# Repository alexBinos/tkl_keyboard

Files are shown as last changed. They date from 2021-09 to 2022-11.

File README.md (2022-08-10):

# tkl_keyboard

A custom tenkeyless keyboard with extra hardware features including;

- ATMEGA32U4 microcontroller compatible with QMK firmware
- 2x optional rotary encoders
- I2C breakout to support an OLED display
- Per-key RGB LED lighting and underglow lighting
- Hot-swap key switch sockets
- 4 port USB 2.0 HUB with 3 spare downstream ports
- Optional external power circuit supplying up to 2A for USB downstream and onboard power requirements

<br>

See `Firmware/` for example QMK projects. Note that some pin assignments changed between v0 and v1, see `Documents/tkl_keyboard v1 changes.md`. Pre-built binaries for the default configurations are also provided in `Firmware/bin`.

<br>

There are two versions of the case, both are compatible with hardware v0 and v1. The v1 case is a more integrated design, easier to assemble and can be positioned at a number of different angles.

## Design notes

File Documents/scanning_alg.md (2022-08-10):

# Matrix scanning algorithm

The matrix scanning algorithm uses negative logic to detect key presses, ie. reading a 0 indicates that a switch has been pressed and driving an output to 0 is to drive it to the 'active' state.
The switch matrix diodes are placed facing from row to column so current can flow in this direction only. The columns are driven as outputs and the rows are read as inputs, the default state is no columns driven, ie. all column outputs are driven to the 1 'inactive' state and the row inputs are allowed to float high by their internal pull-up resistor.
The matrix is scanned with the following method;

1. Drive the first column output low while leaving all other column outputs high
2. Read back all row values simultaneously
3. Drive the current column high
4. Drive the next column low while leaving all other column outputs high
5. Repeat from step 2

When a switch is pressed, the path between the microcontrollers internal pull-up resistor and the diode is closed. When the corresponding column drives low the diode is allowed to conduct and a low is seen at the microcontroller row input pin. The columns are scanned much faster than a switch press event to guarantee that every switch press is captured.

A switch press event is processed when the rows are read back; if one or more of the row values are low then the switch(s) located at position (row, col) is being pressed. Note that the diodes allow any keyswitch combination to be decoded uniquely. Since the switch press is recorded in negative logic, the final result is inverted in the firmware before handing over to the switch decoding logic where the matrix position is mapped to a key switch value.

<p align="center" width="100%">
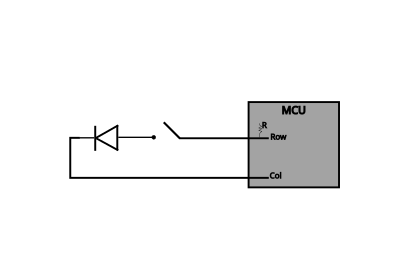
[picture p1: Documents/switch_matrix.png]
     
</p>

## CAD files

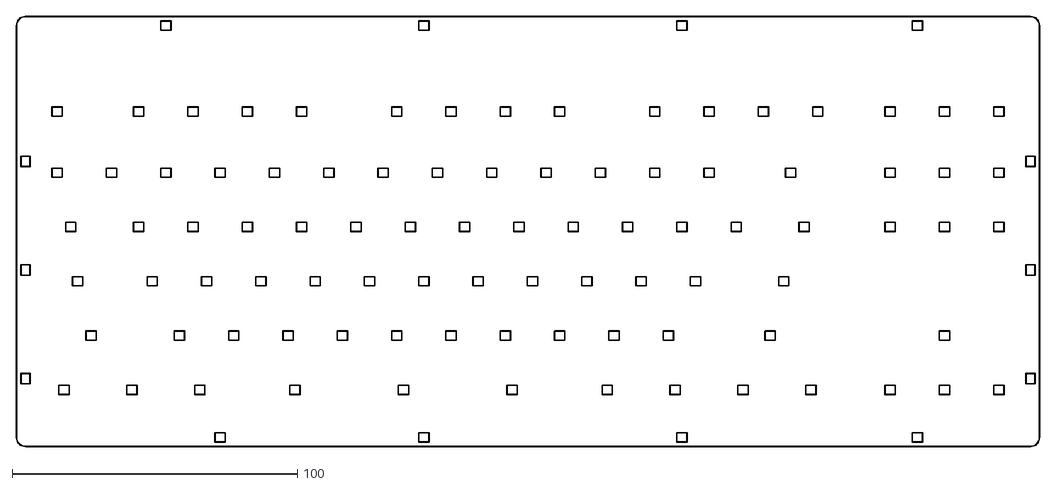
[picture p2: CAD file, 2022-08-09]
Mechanical/dxf/tkl_keyboard-Edge_Cuts.dxf
358.8 x 150.9

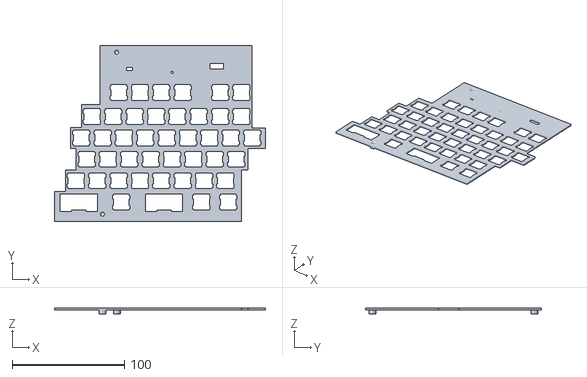
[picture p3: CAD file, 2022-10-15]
Mechanical/v1/tkl_keyframe_middle.STL
188.2 x 156.9 x 5.40

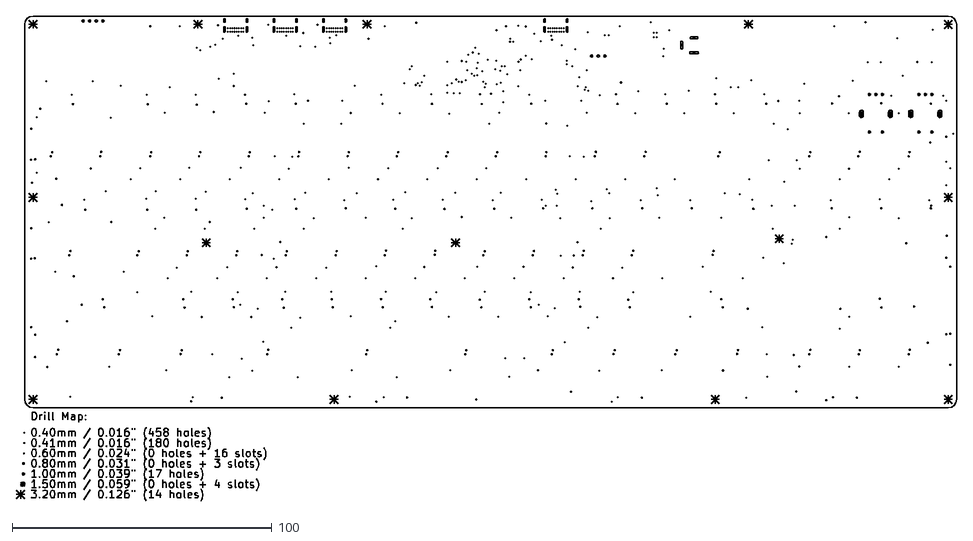
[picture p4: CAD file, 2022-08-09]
Mechanical/dxf/tkl_keyboard-PTH-drl_map.dxf
362.0 x 186.7

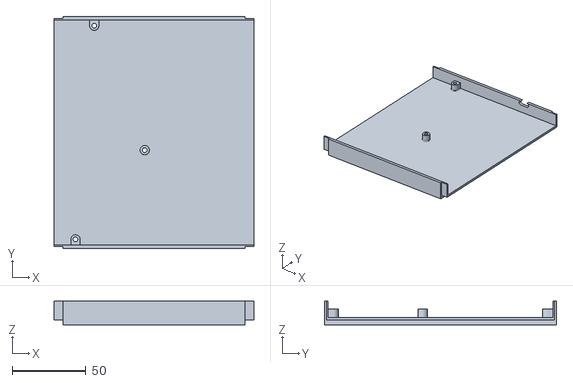
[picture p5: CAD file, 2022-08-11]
Mechanical/v1/tkl_case_middle.STL
135.2 x 156.9 x 16.0

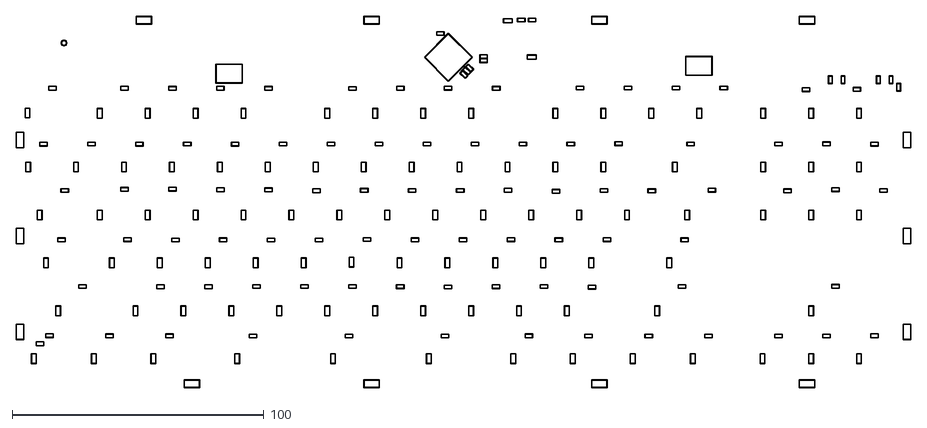
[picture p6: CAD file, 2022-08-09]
Mechanical/dxf/tkl_keyboard-B_CrtYd.dxf
355.5 x 147.5

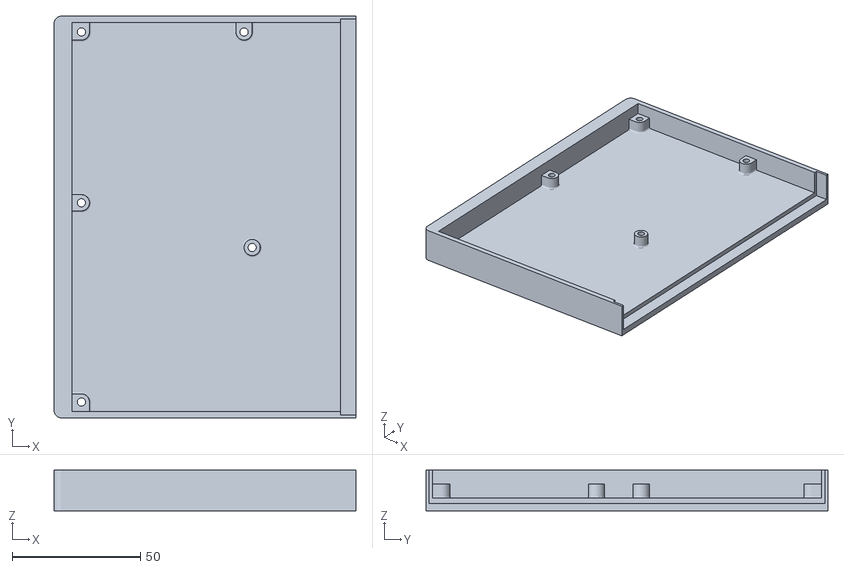
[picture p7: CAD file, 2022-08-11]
Mechanical/v1/tkl_case_left.STL
117.9 x 156.9 x 16.0

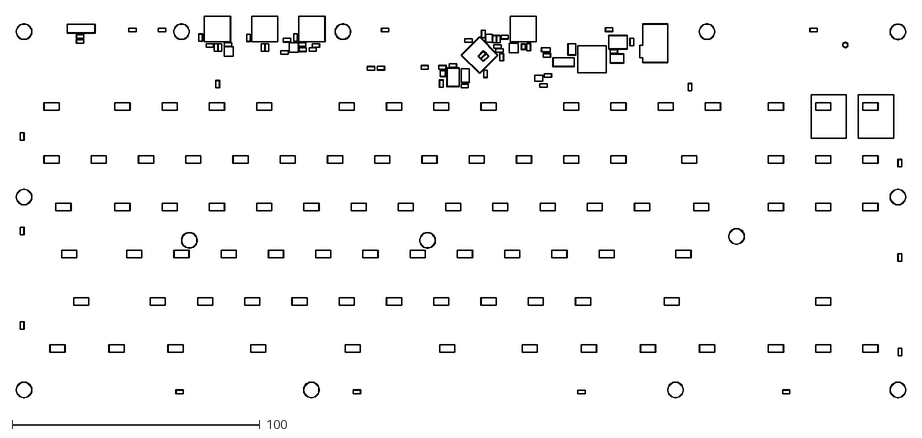
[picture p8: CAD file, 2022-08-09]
Mechanical/dxf/tkl_keyboard-F_CrtYd.dxf
358.7 x 153.8

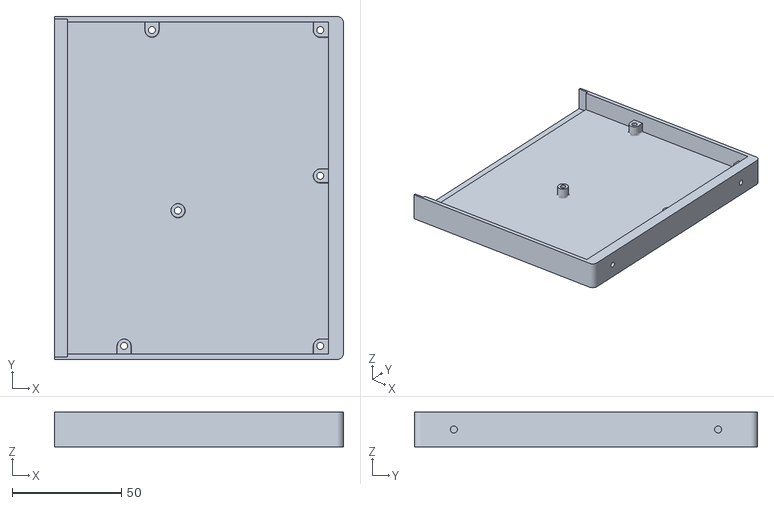
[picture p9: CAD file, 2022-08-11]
Mechanical/v1/tkl_case_right.STL
132.3 x 156.9 x 16.0

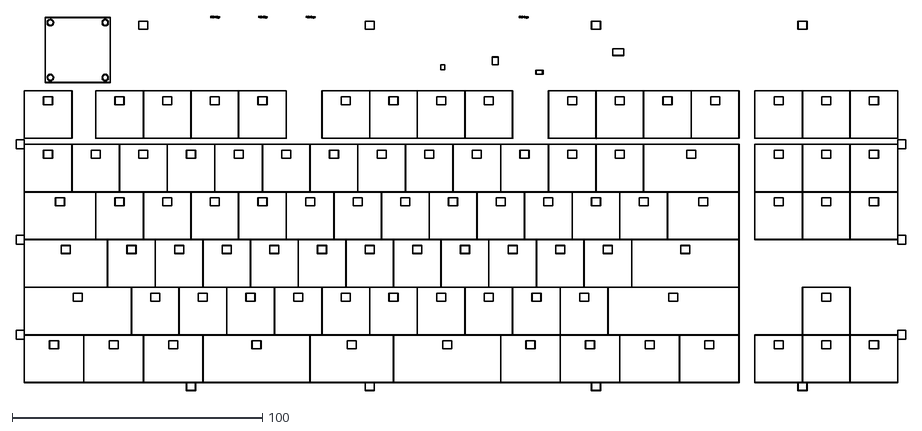
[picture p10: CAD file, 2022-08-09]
Mechanical/dxf/tkl_keyboard-Dwgs_User.dxf
355.7 x 149.6

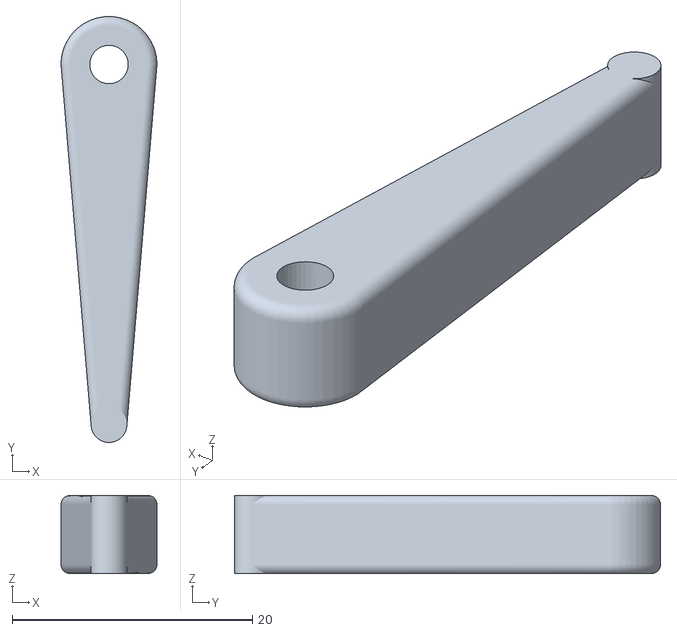
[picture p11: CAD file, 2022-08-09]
Mechanical/v1/tkl_stand.STL
8.00 x 35.5 x 6.50

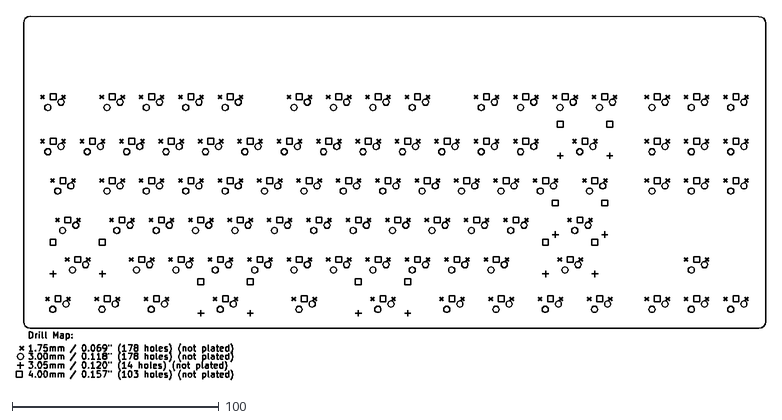
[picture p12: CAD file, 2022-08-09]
Mechanical/dxf/tkl_keyboard-NPTH-drl_map.dxf
362.2 x 175.5

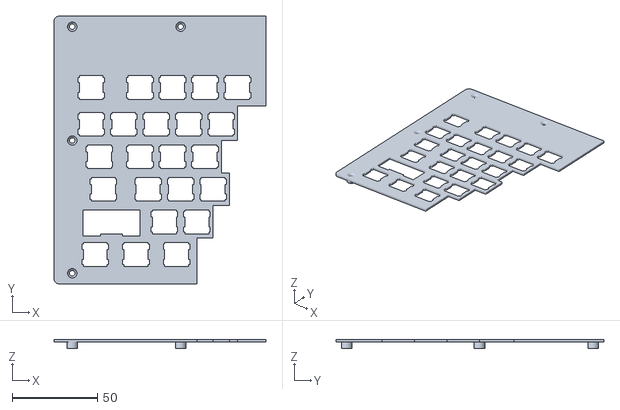
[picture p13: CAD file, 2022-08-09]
Mechanical/v1/tkl_keyframe_left.STL
124.2 x 156.9 x 5.40

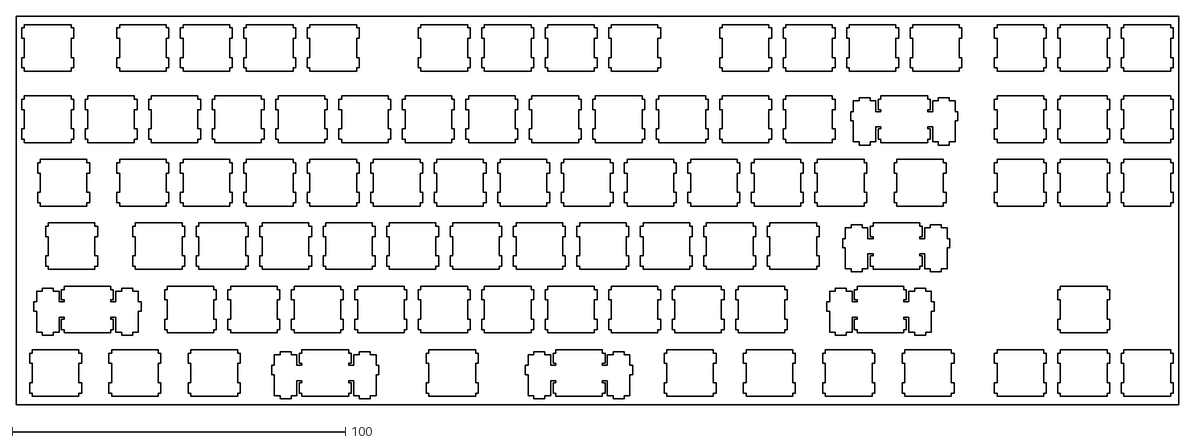
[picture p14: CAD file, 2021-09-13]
Mechanical/dxf/mx_key_frame_swillkb.dxf
349.2 x 116.7

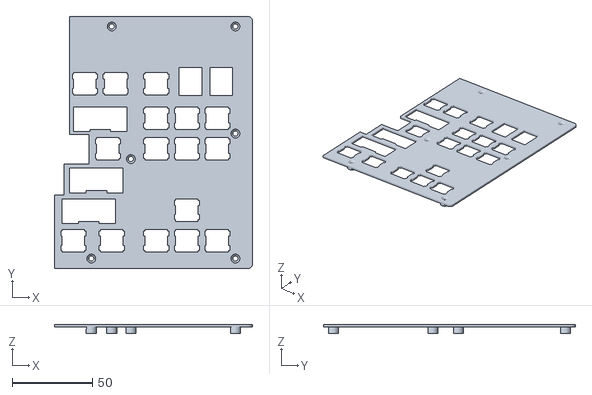
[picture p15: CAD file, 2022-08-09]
Mechanical/v1/tkl_keyframe_right.STL
123.4 x 156.9 x 5.40

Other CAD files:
Mechanical/v0/tkl_bottom_middle.STL
Mechanical/v0/tkl_bottom_right.STL
Mechanical/v0/tkl_key_frame_middle.STL
Mechanical/v0/tkl_bottom_left.STL
Mechanical/v0/tkl_key_frame_left.STL
Mechanical/v0/tkl_key_frame_right.STL
Mechanical/v0/tkl_spacer.STL

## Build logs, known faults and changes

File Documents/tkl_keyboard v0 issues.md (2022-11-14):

## TKL Keyboard v0 issues

<br>

1. I2C lines connected incorrectly to ATMEGA32U4

The I2C lines are not connected to the dedicated I2C hardware pins PD1 and PD0 on the ATMEGA32U4. The OLED display cannot be driven on the v0 board.

*Fixes:* Cannot be fixed in hardware as the dedicated I2C pins are used to drive the switch matrix.

2. Line decoders are never disabled

In order for the matrix scanning algorithm to work correctly, each line decoder output needs to be disabled (set to 0xFF) while the other side of the matrix is being scanned.

*Fixes:* This can be achieved by driving pin 6, E3 low. Pins from rotary encoder 2 were repurposed to make this connection on the v0 board. The V1 board features just 2 rotary encoders as a result.

<p align="center" width="100%">
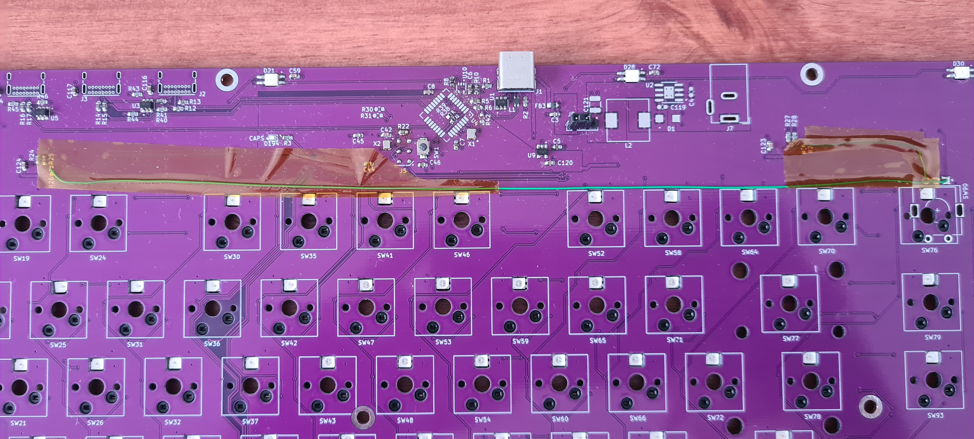
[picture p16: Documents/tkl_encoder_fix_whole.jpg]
    
</p>

<p align="center" width="100%">
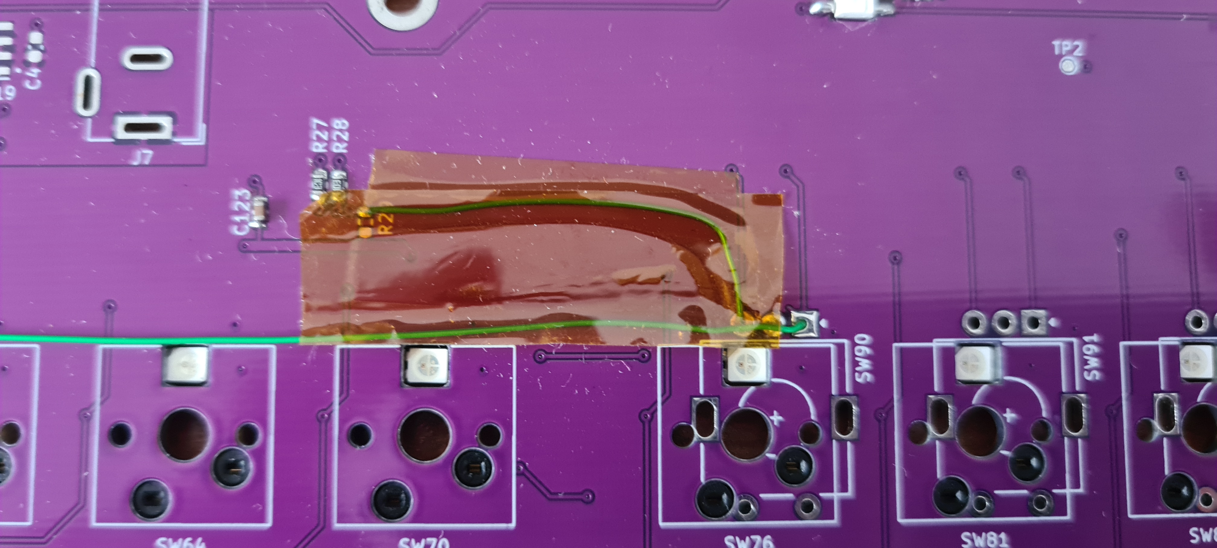
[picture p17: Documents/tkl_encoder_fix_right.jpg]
    
</p>

<p align="center" width="100%">
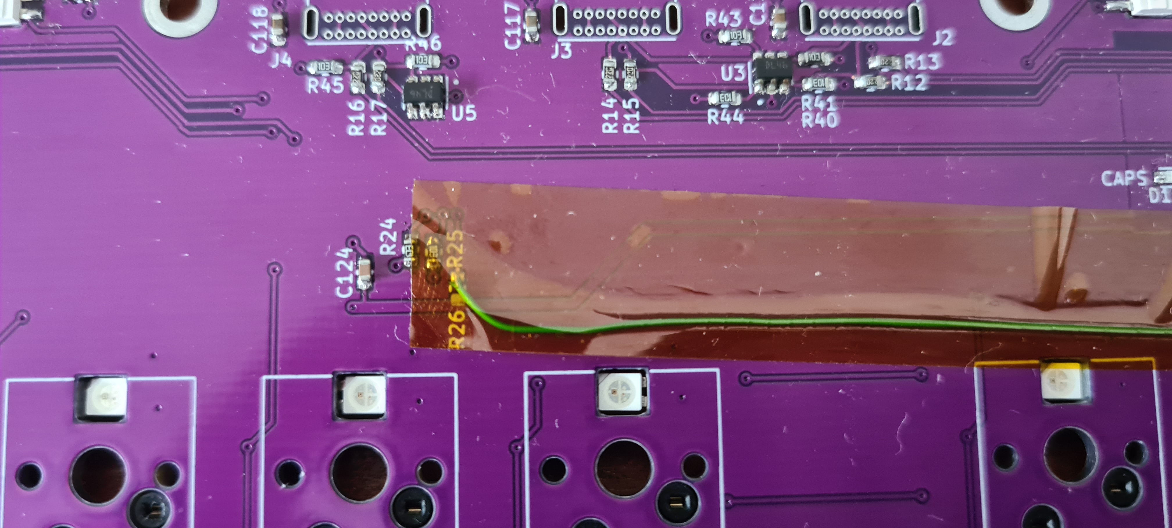
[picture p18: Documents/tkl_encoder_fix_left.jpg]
    
</p>

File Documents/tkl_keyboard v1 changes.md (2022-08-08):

## TKL Keyboard v1 changes

<br>

   1. Moved I2C lines to PD1/SDA and PD0/SCL
   2. Removed line decoder strap resistors
   3. Disconnected mouting holes from ground
   4. Rounded corners on +3V3 plane

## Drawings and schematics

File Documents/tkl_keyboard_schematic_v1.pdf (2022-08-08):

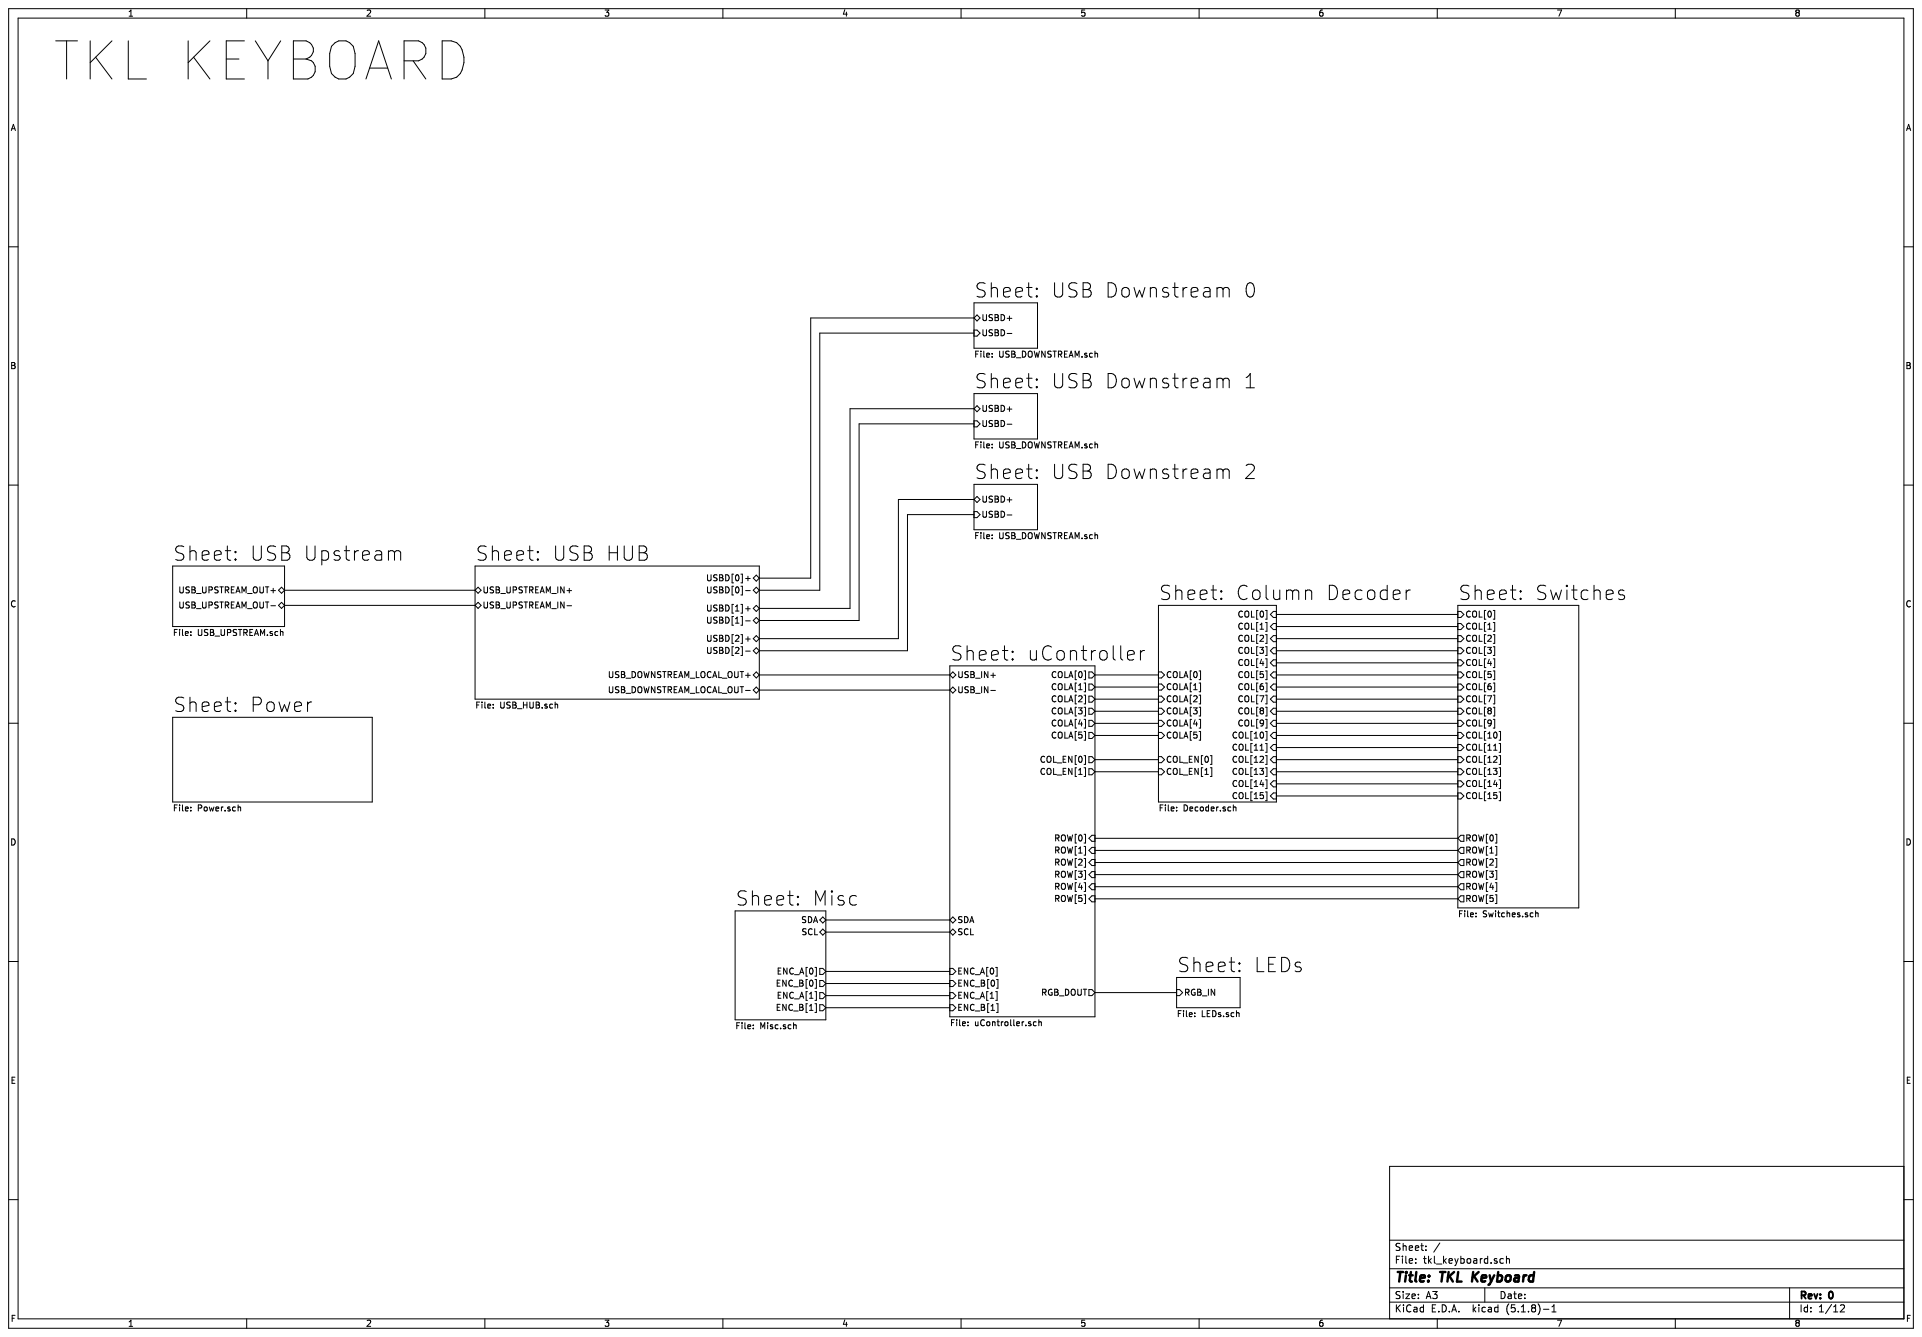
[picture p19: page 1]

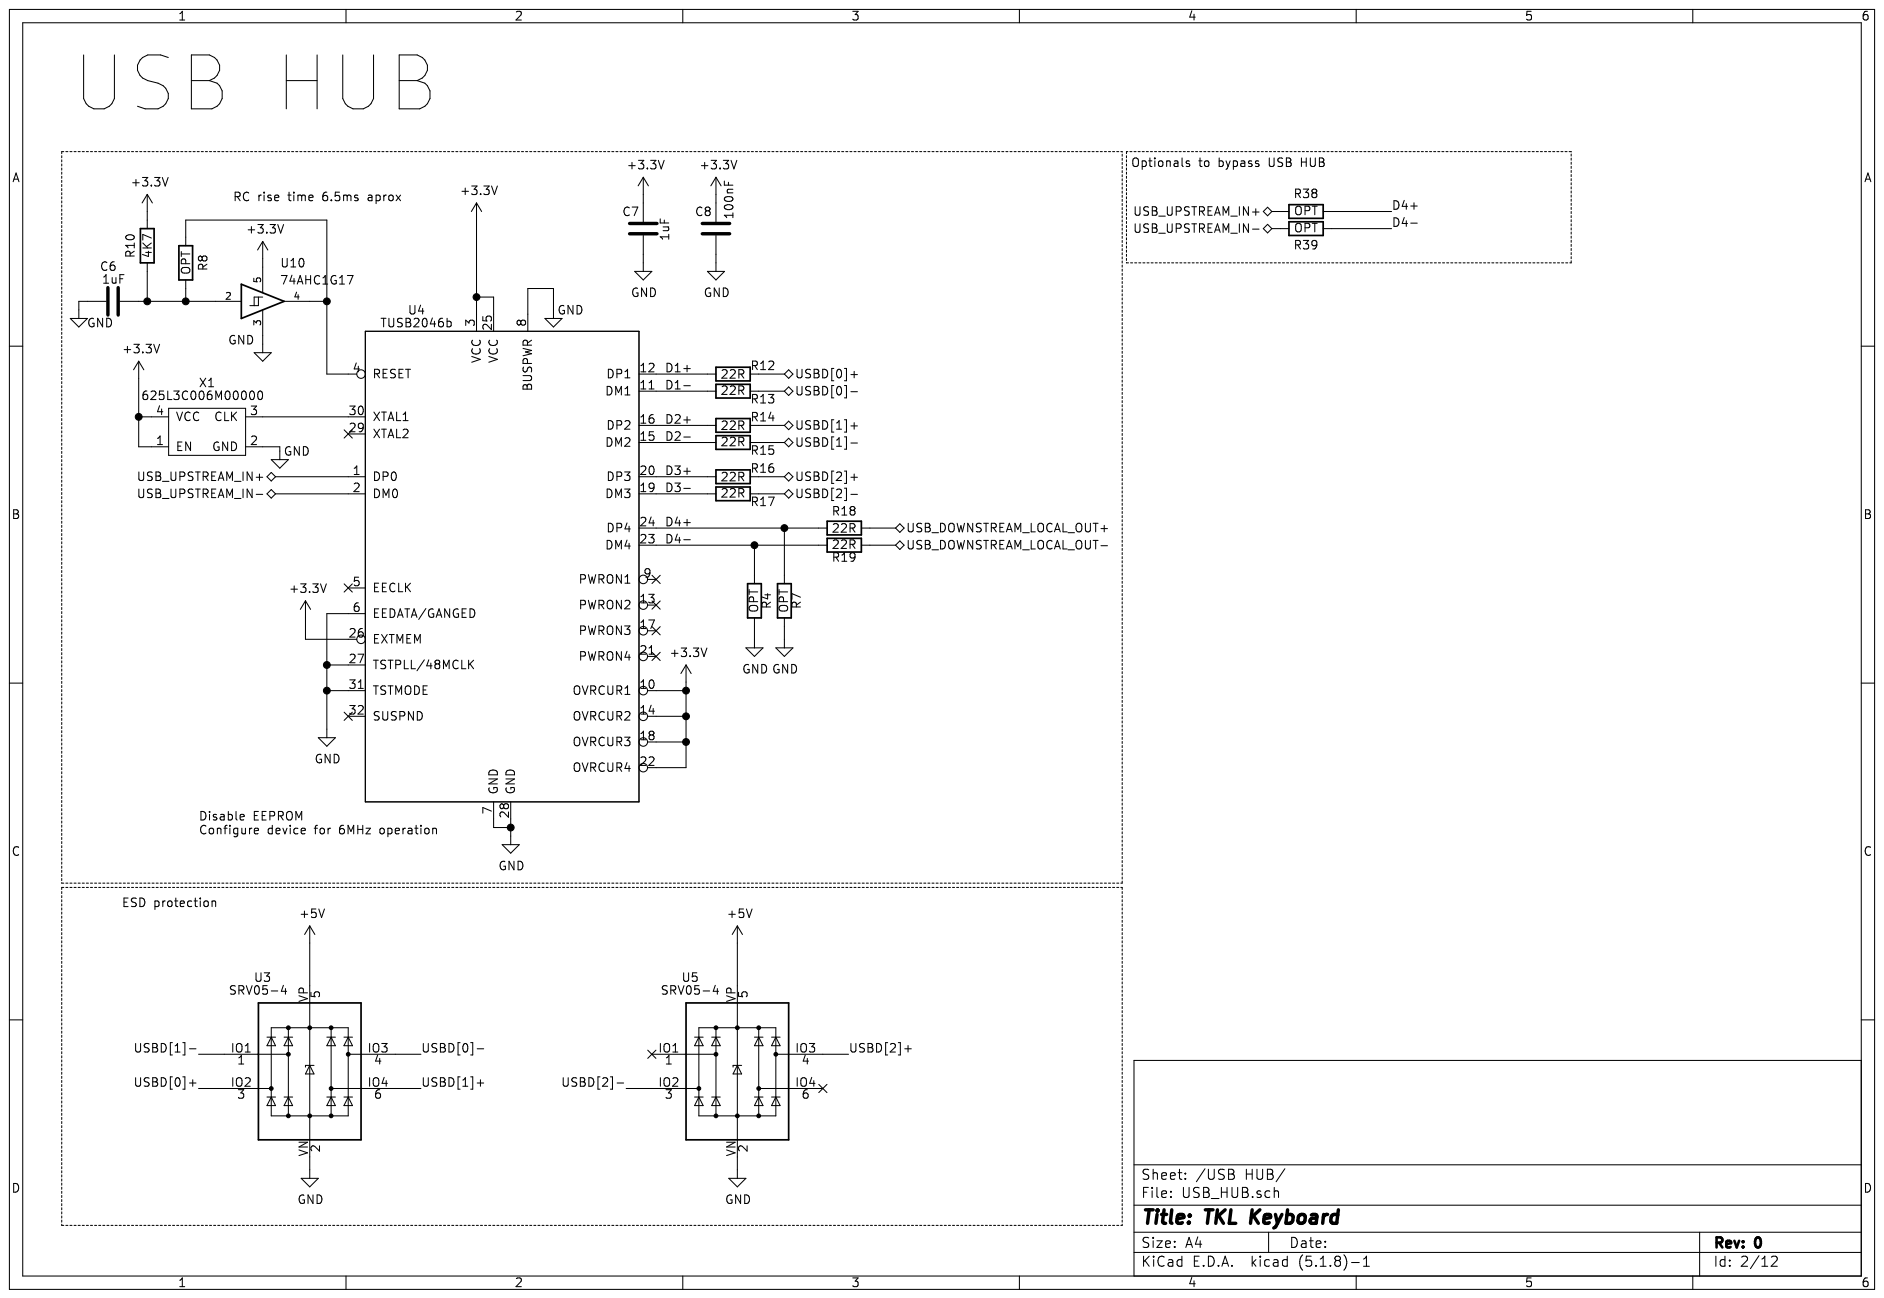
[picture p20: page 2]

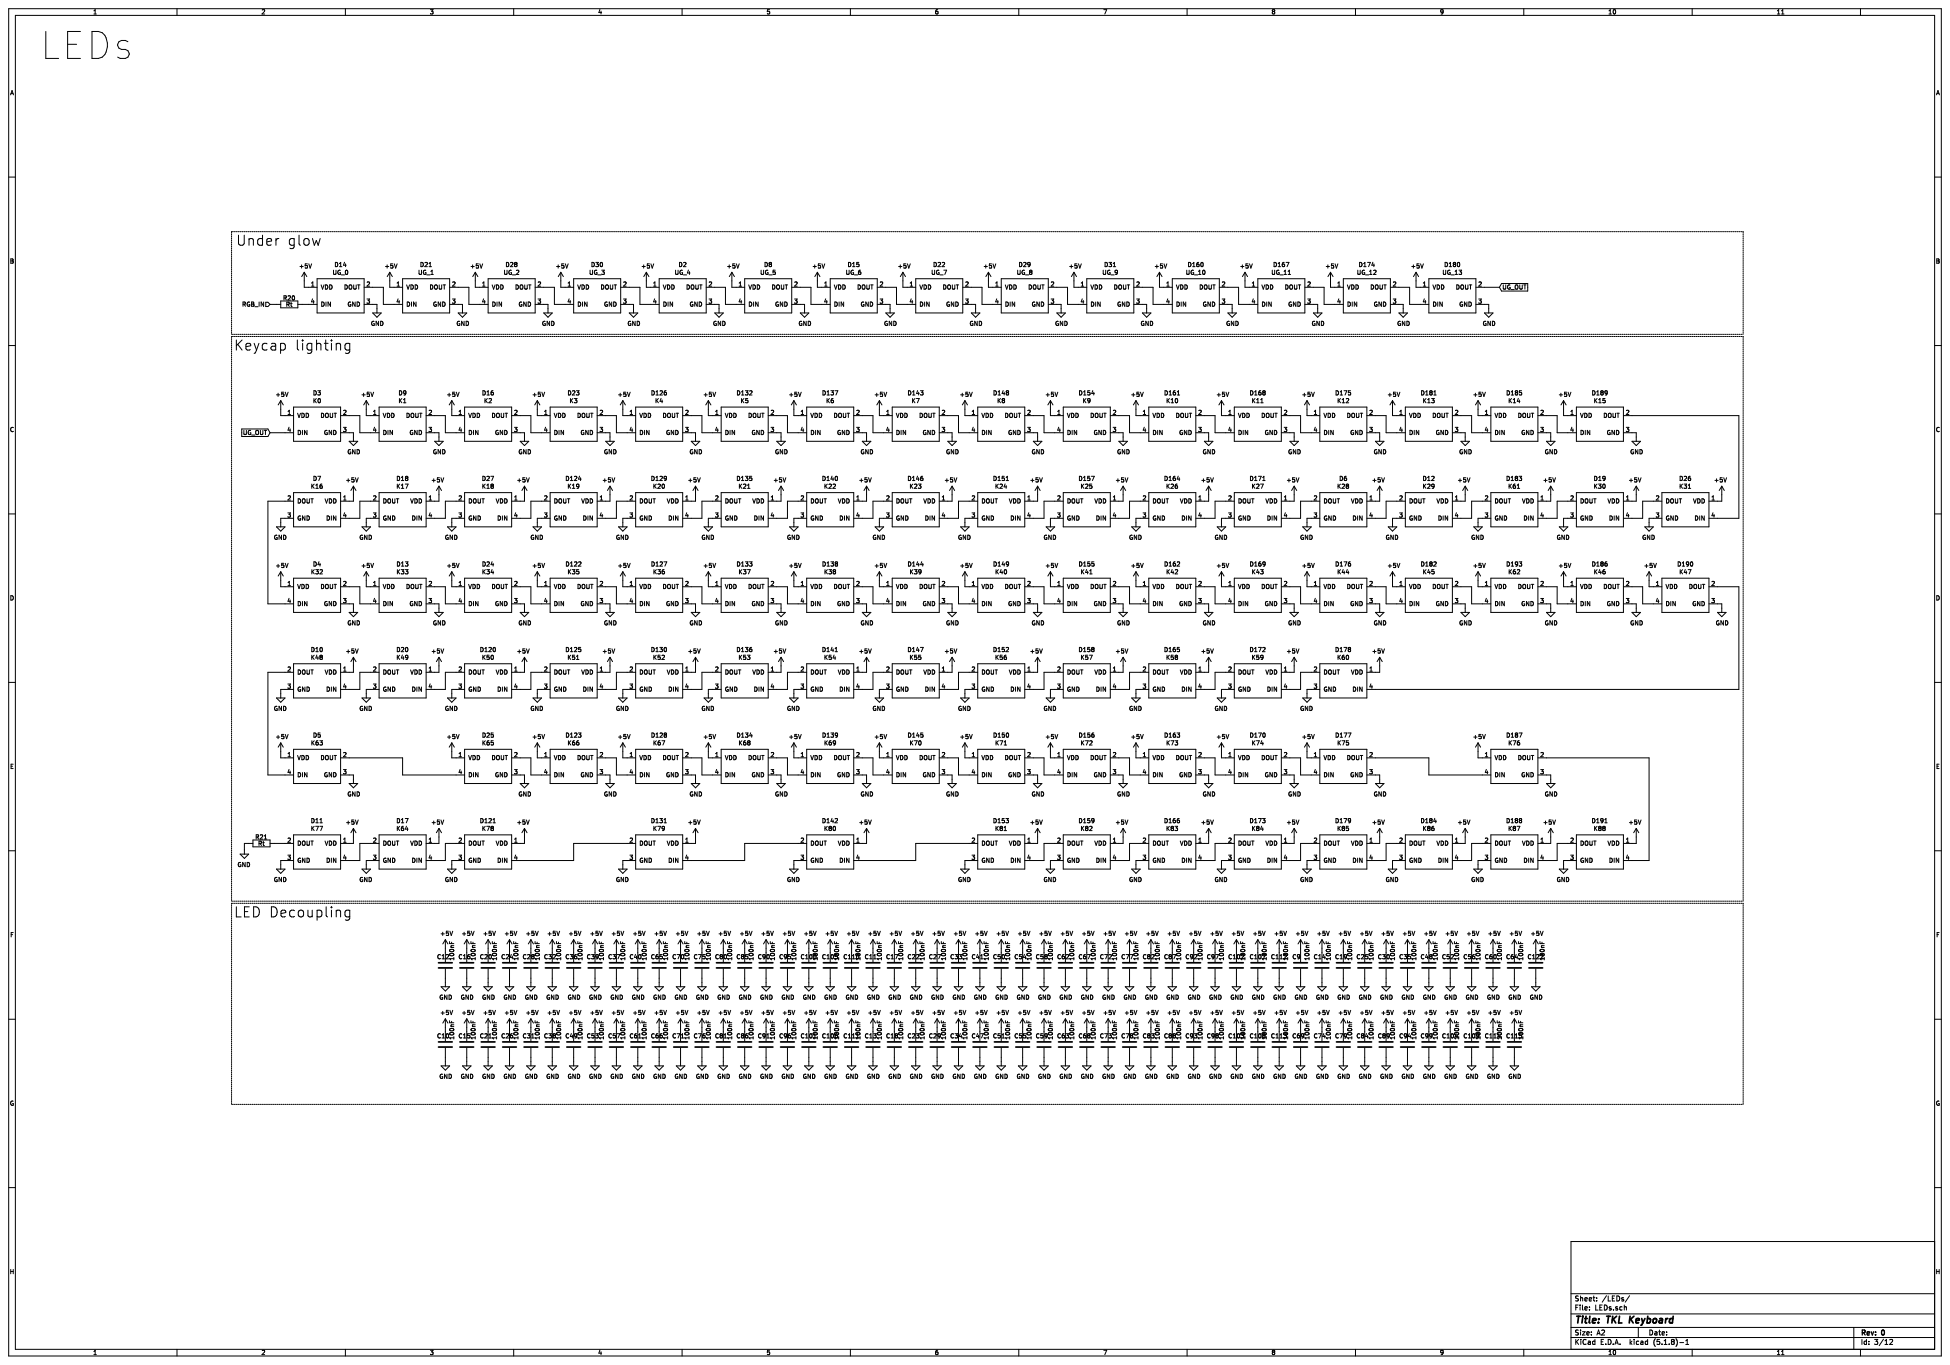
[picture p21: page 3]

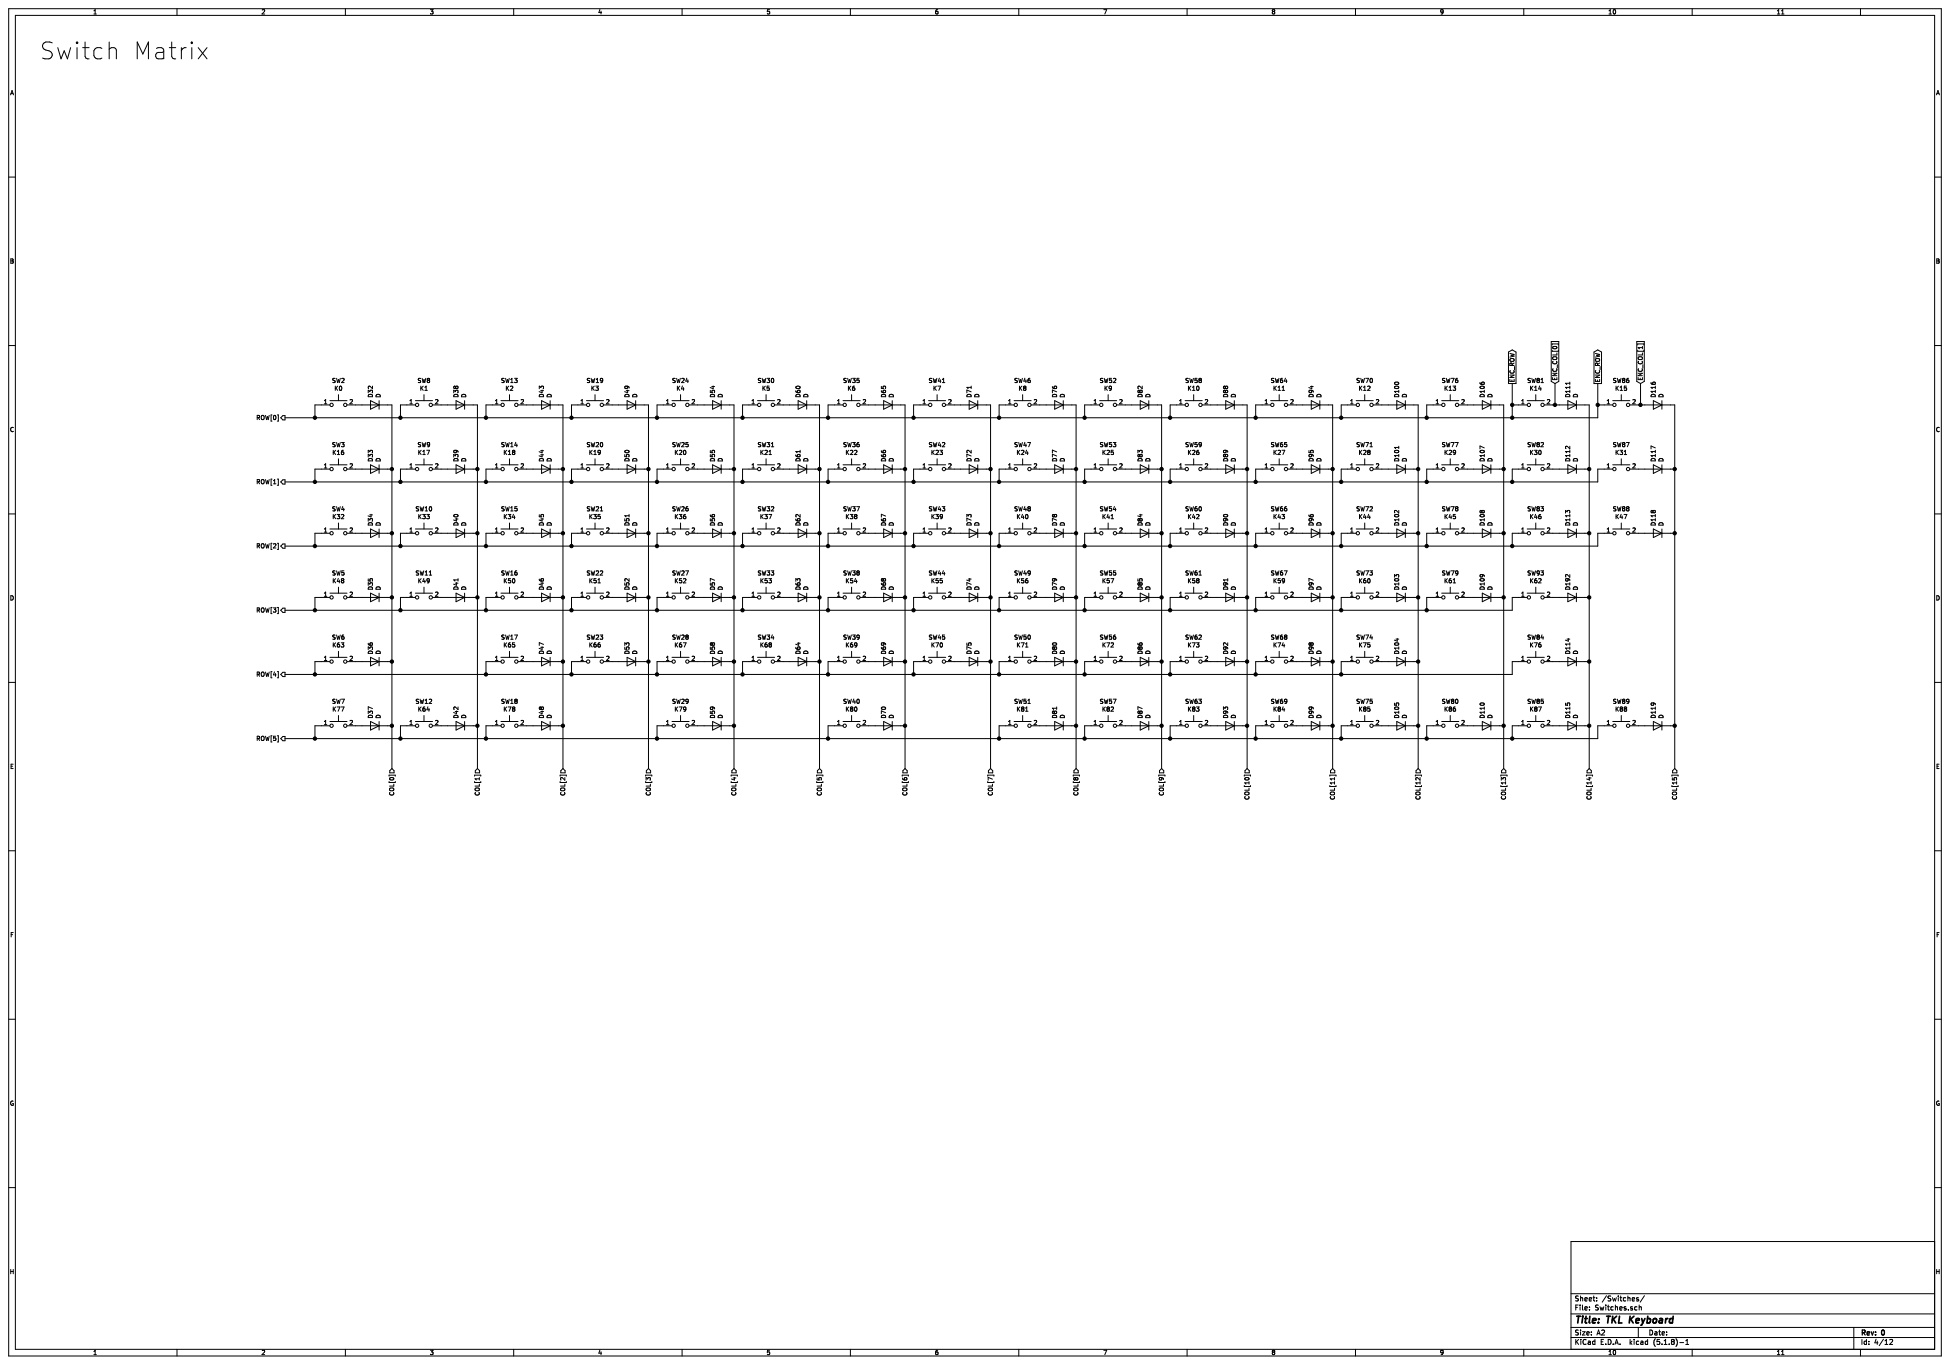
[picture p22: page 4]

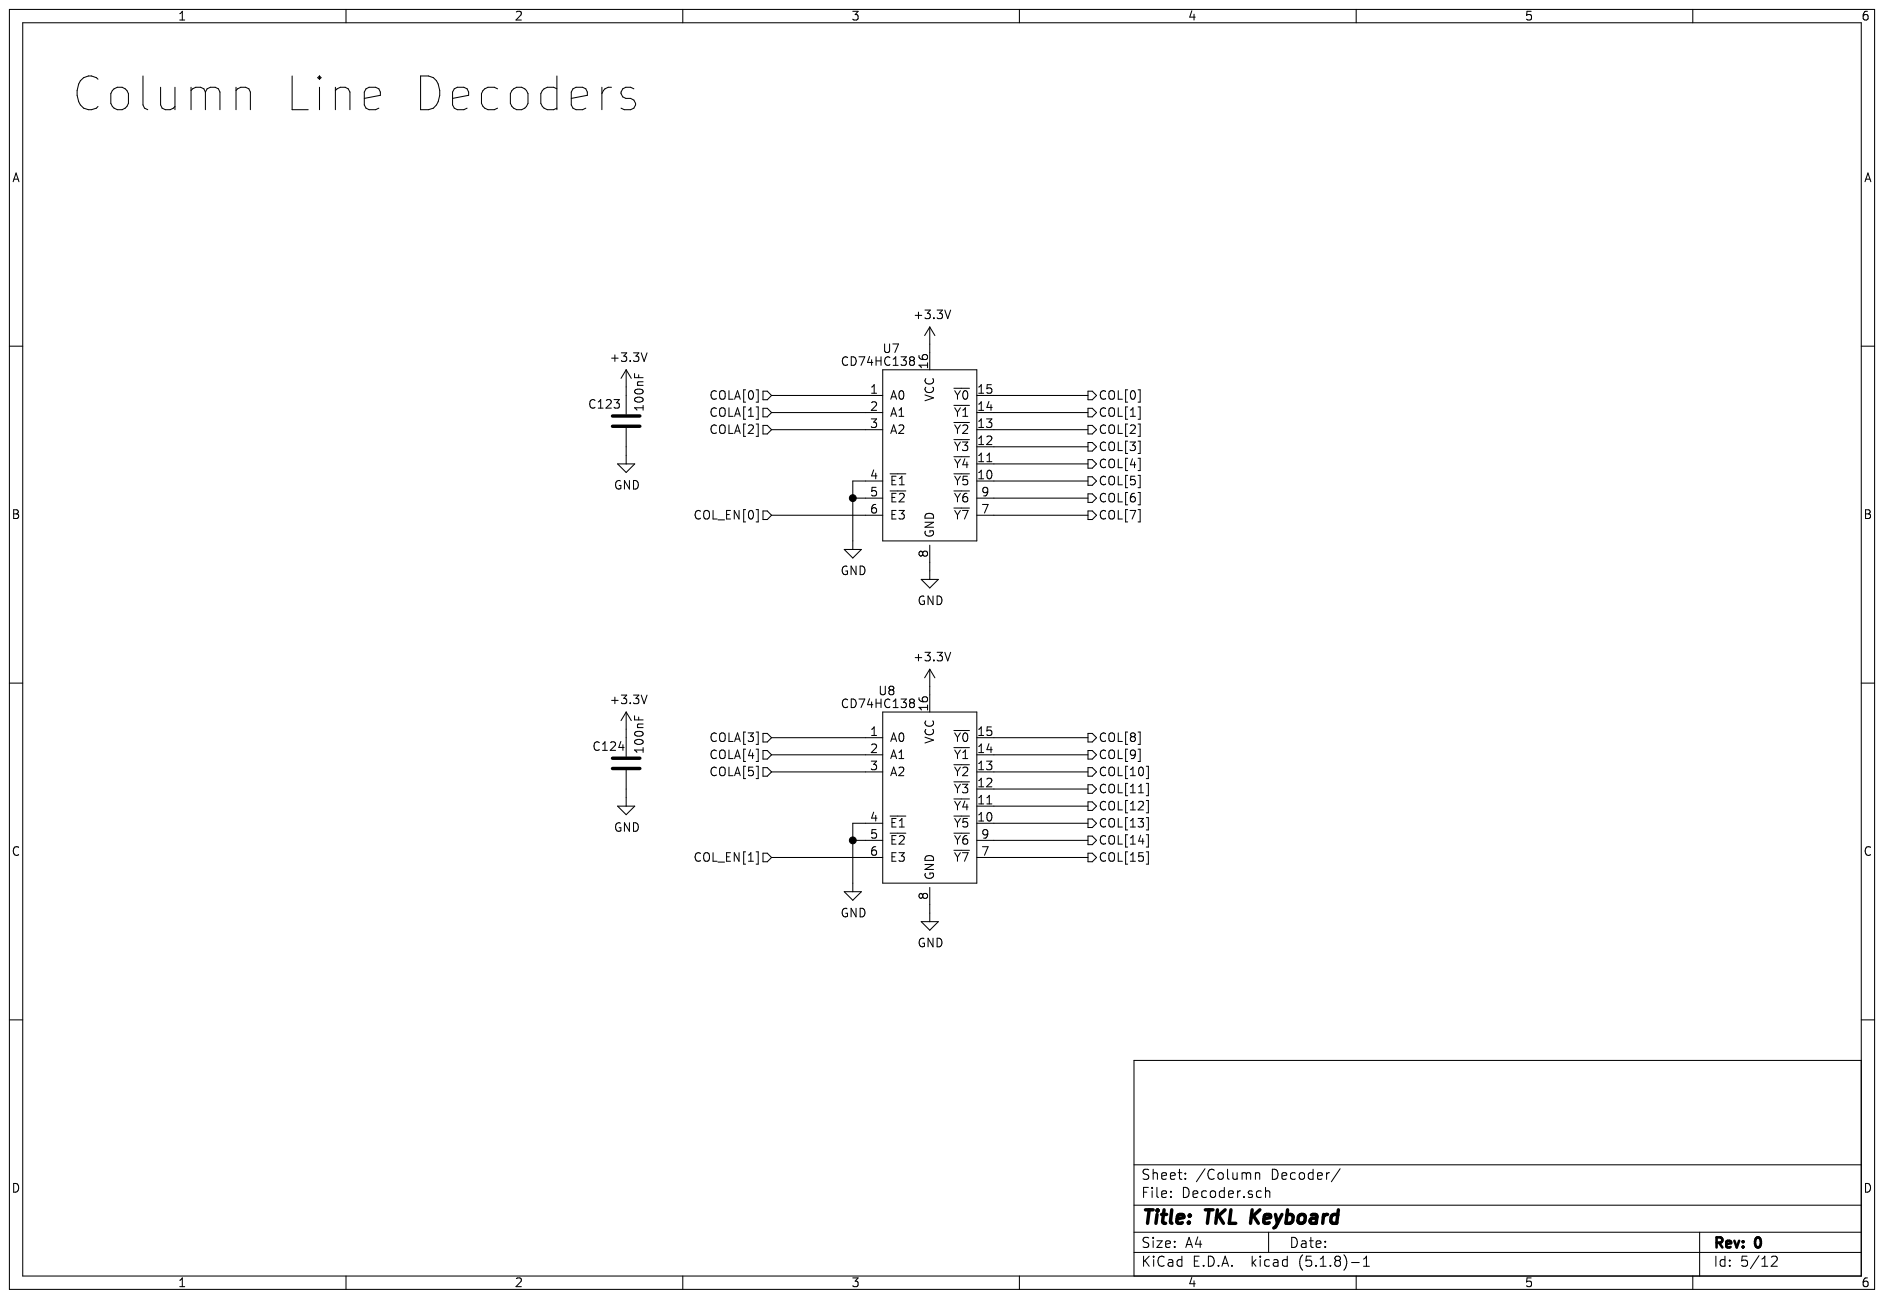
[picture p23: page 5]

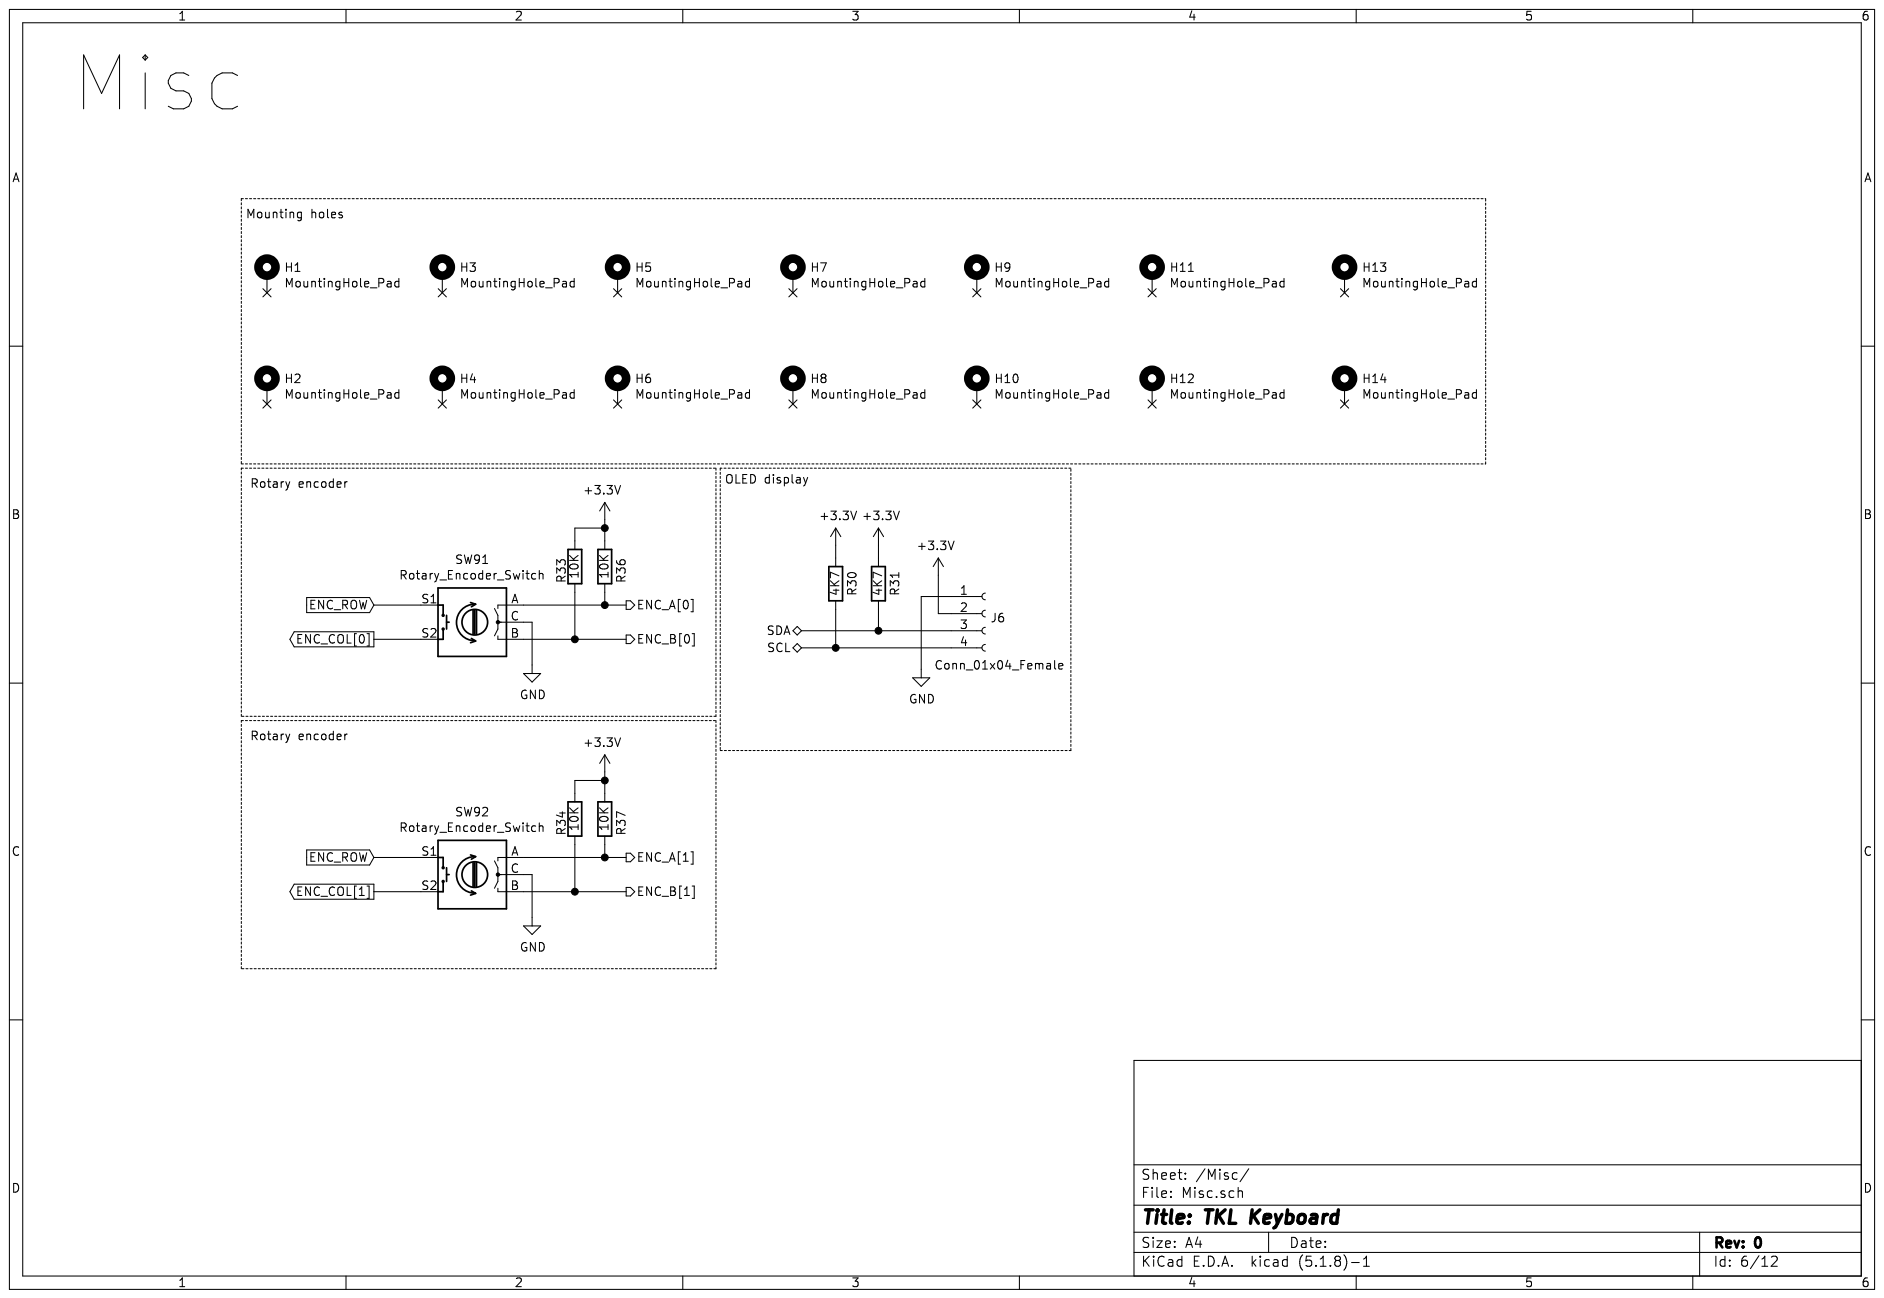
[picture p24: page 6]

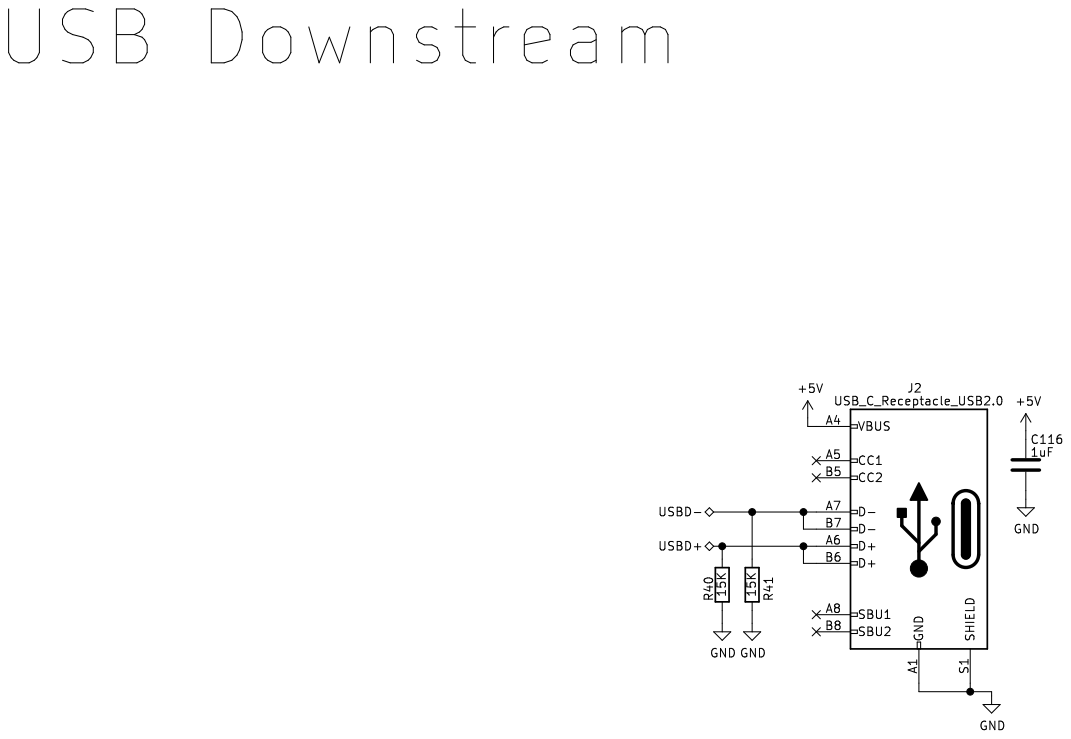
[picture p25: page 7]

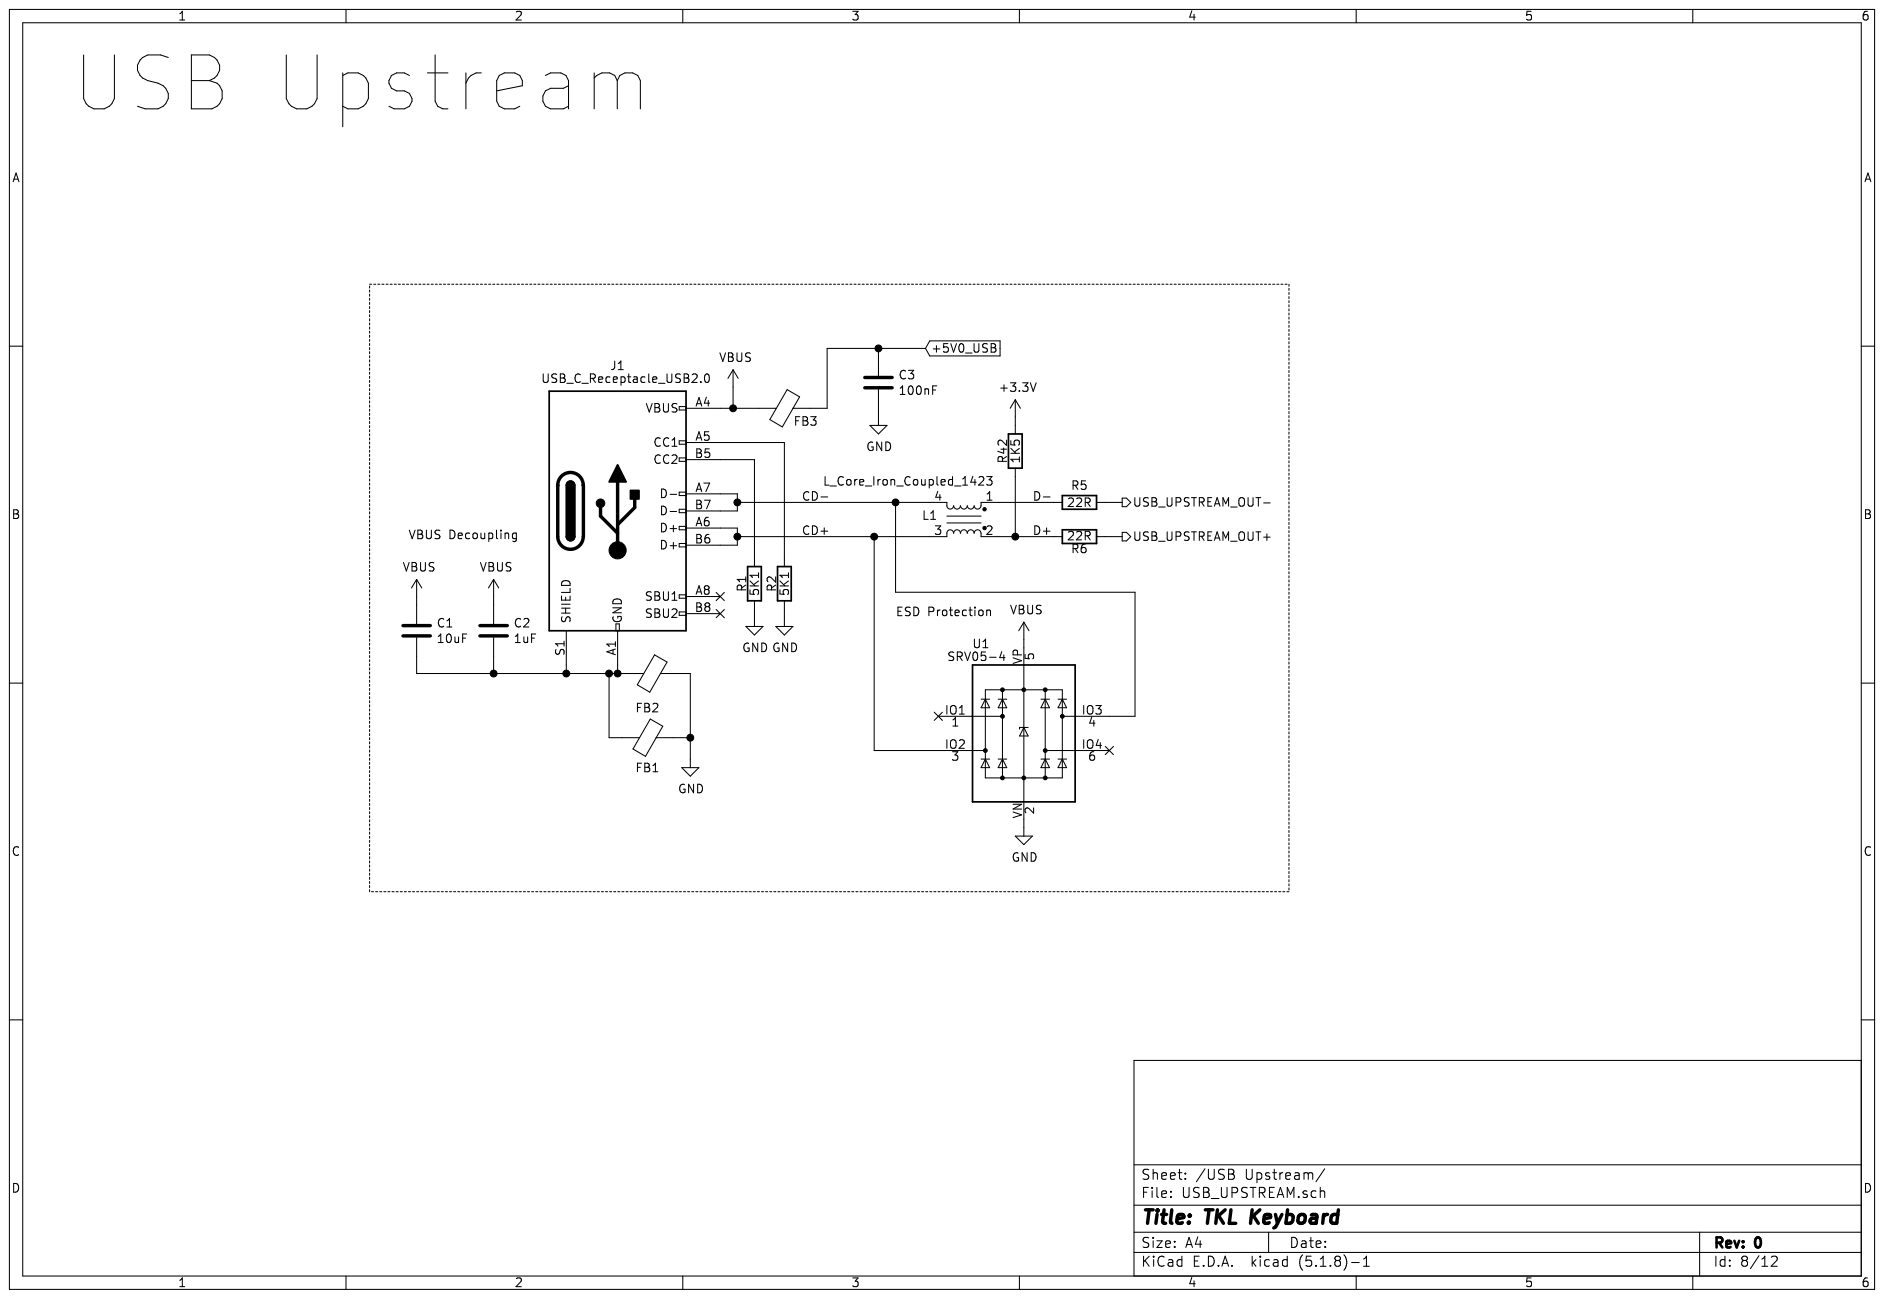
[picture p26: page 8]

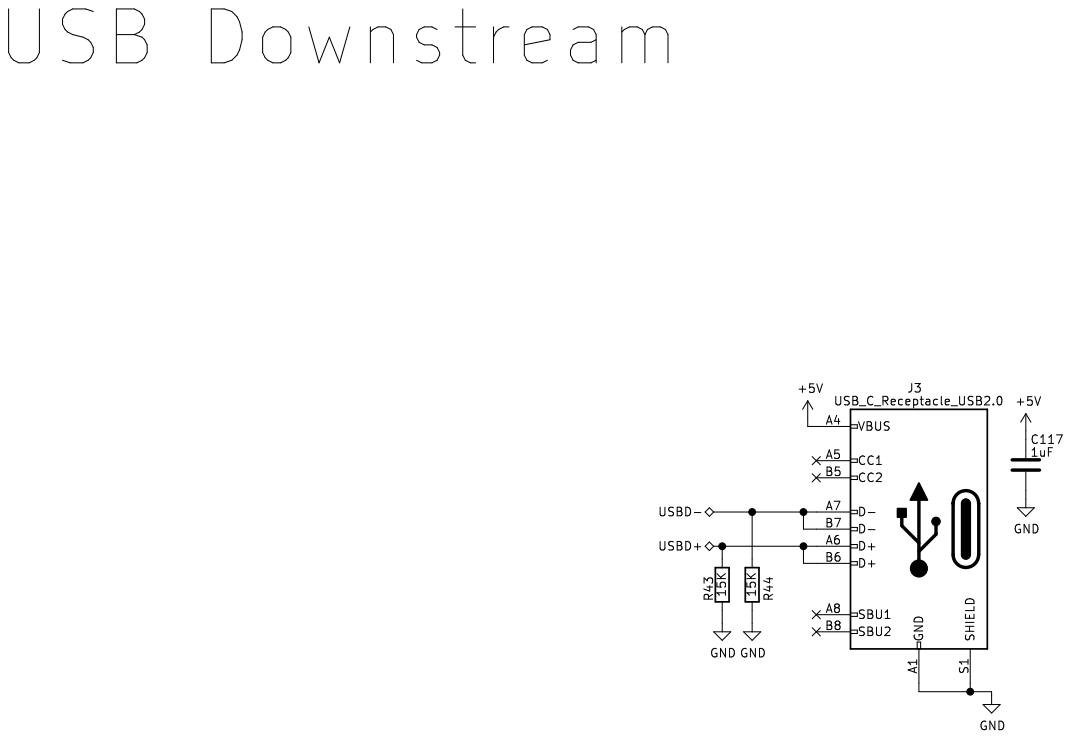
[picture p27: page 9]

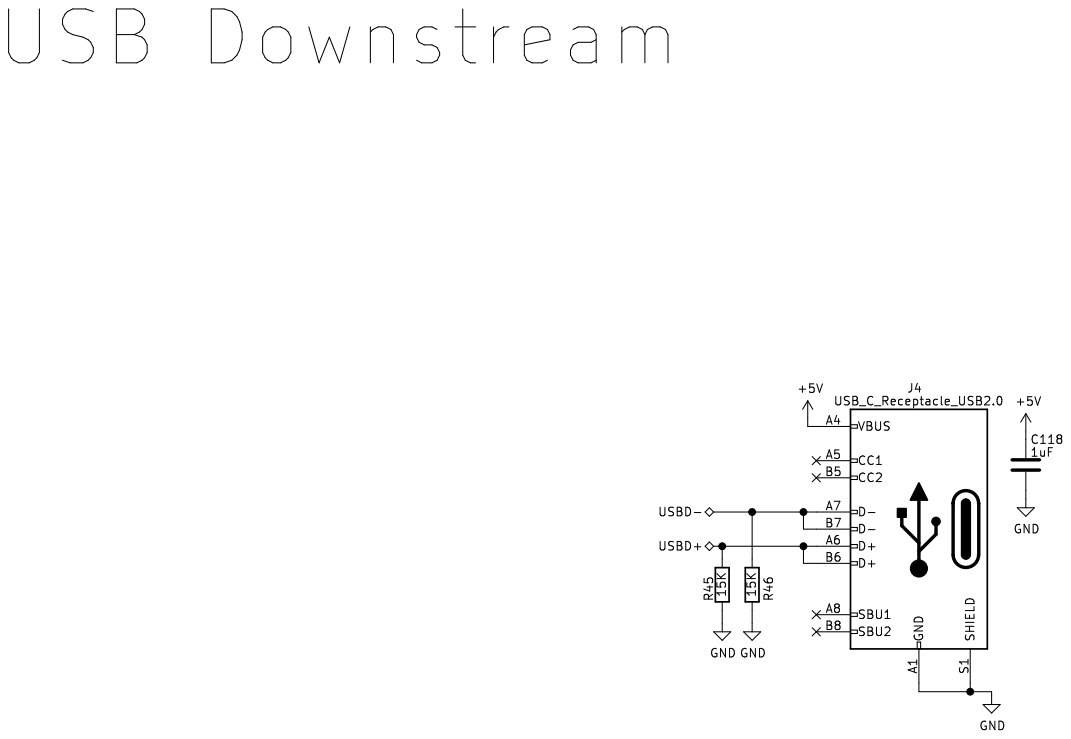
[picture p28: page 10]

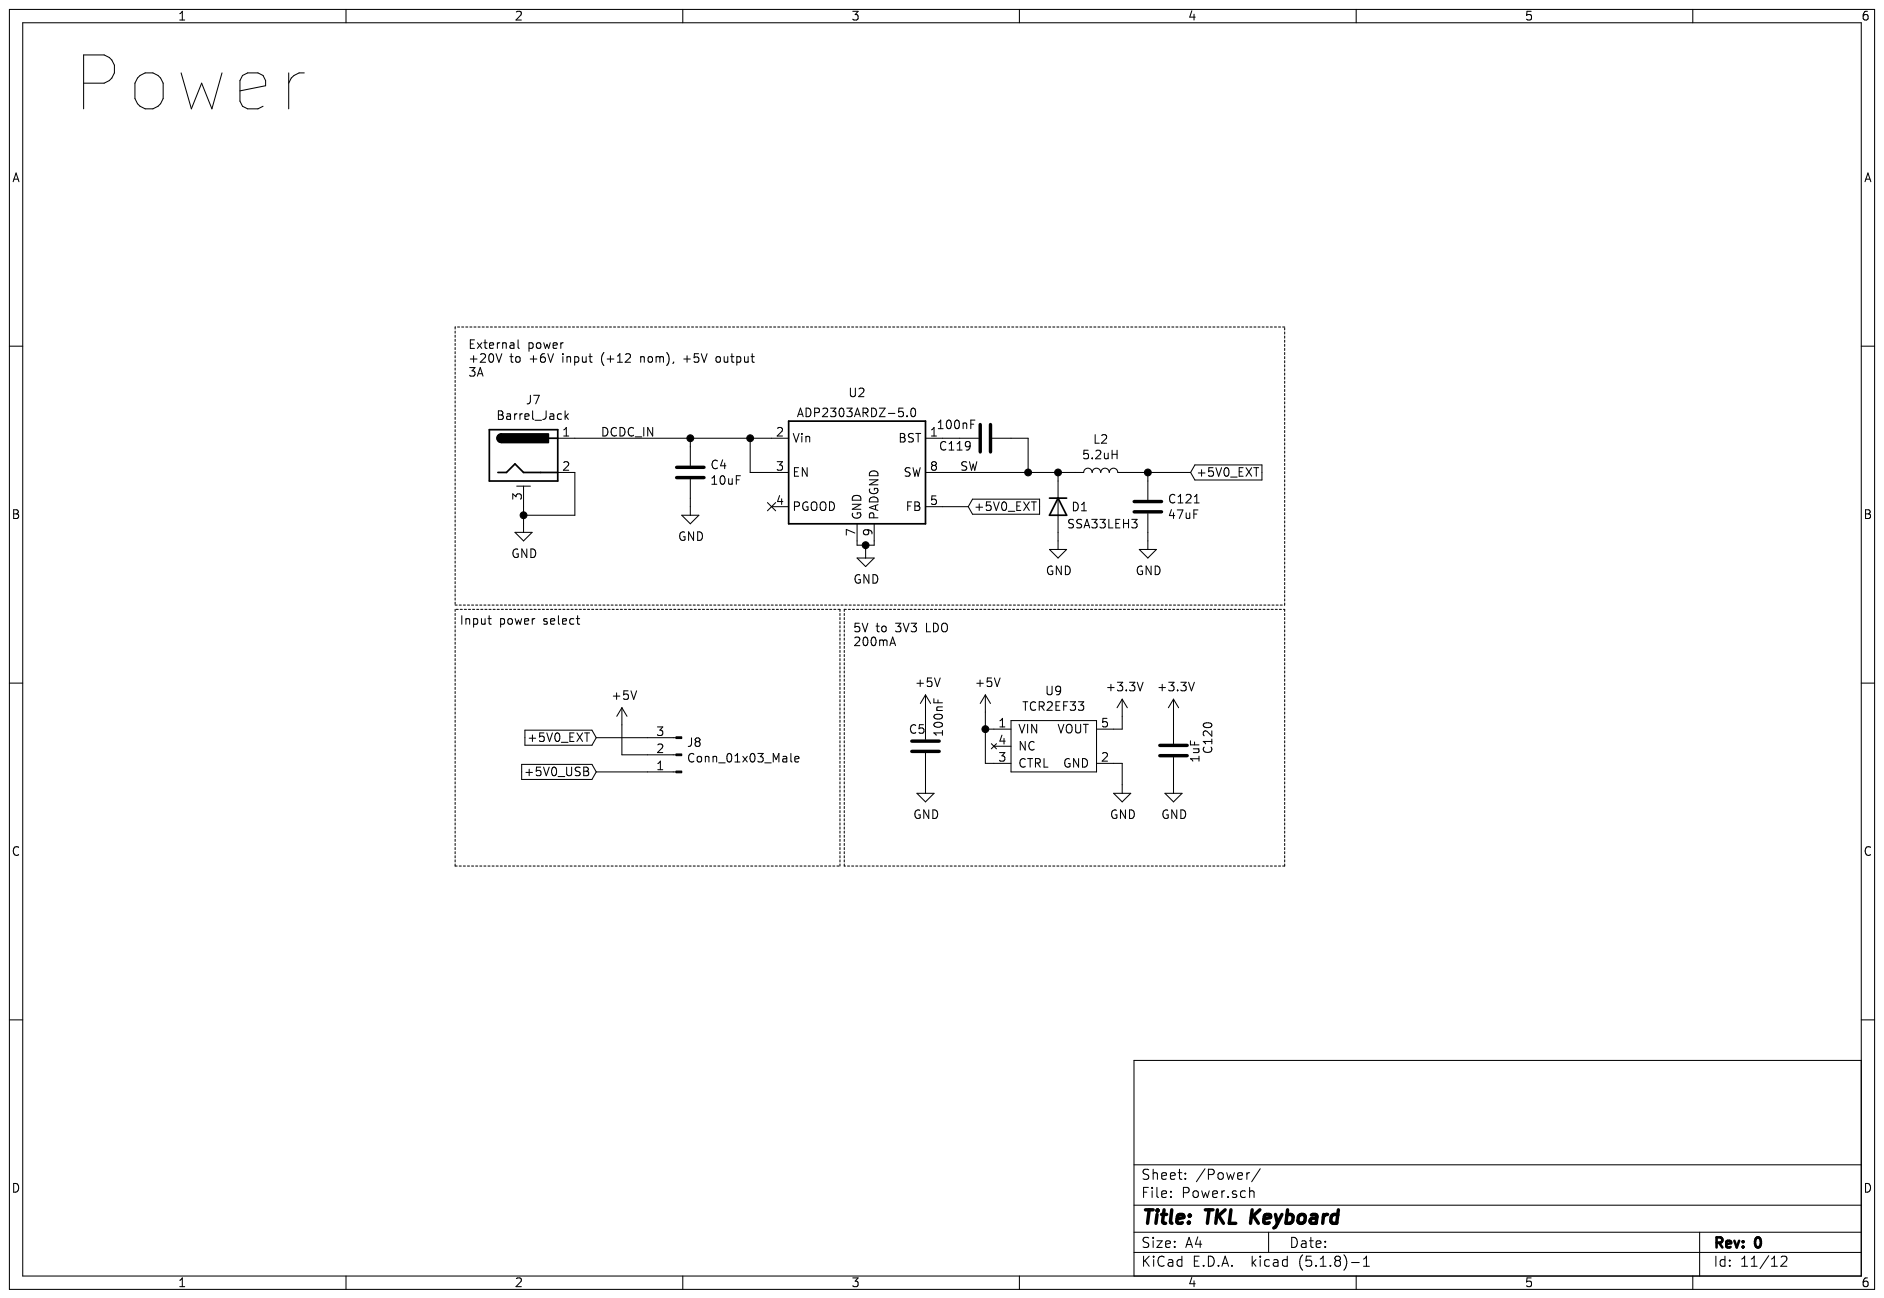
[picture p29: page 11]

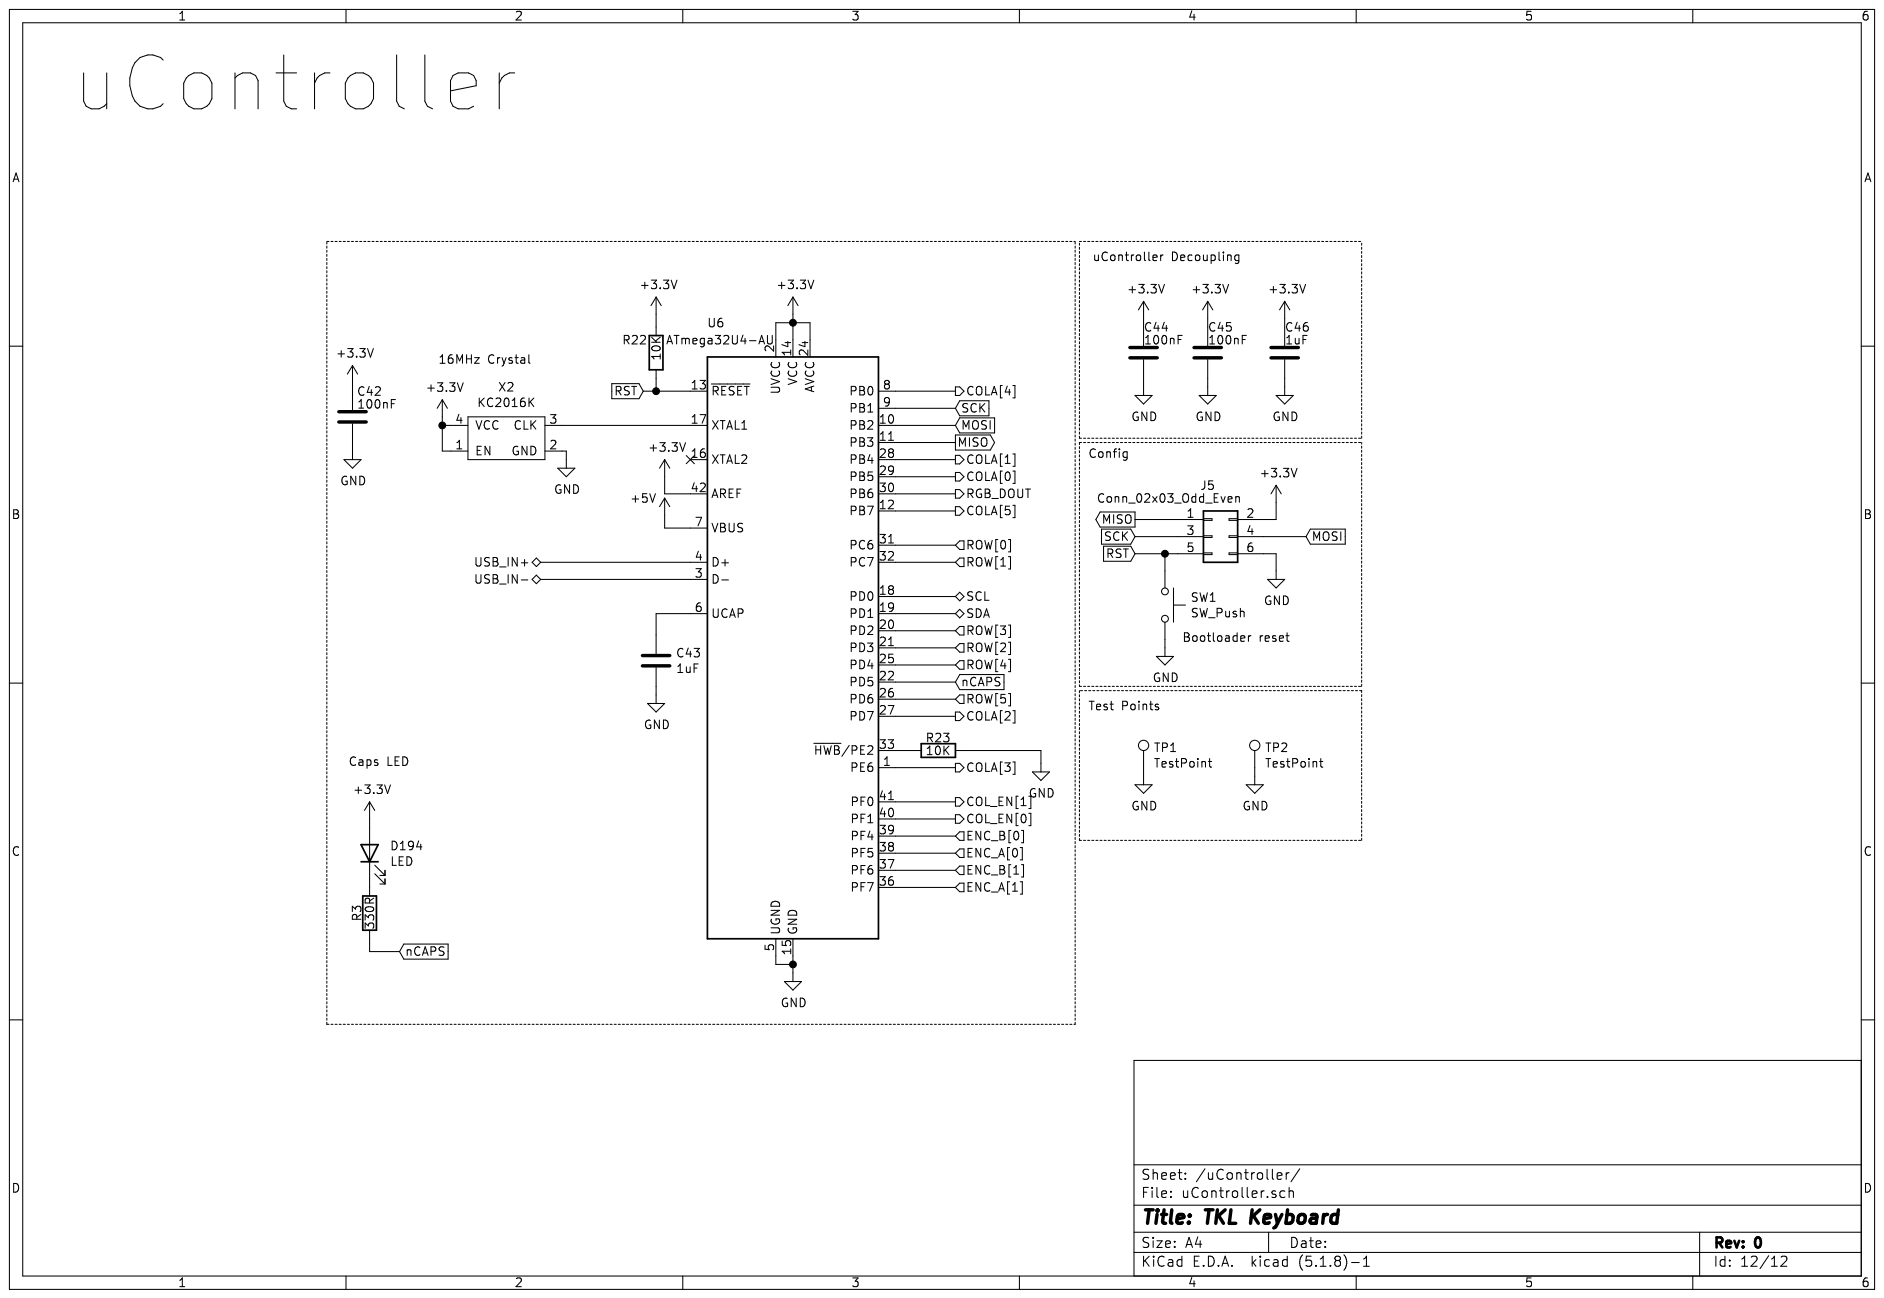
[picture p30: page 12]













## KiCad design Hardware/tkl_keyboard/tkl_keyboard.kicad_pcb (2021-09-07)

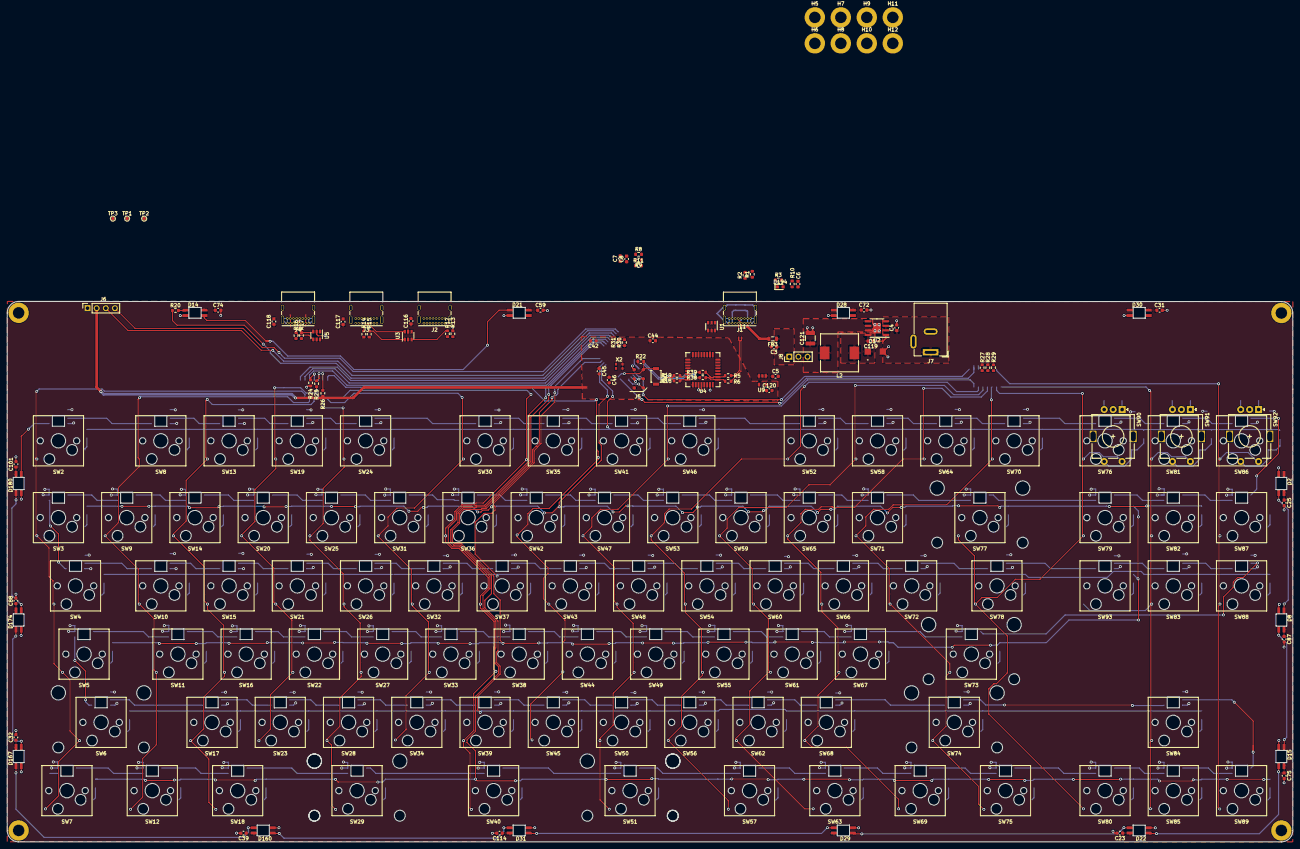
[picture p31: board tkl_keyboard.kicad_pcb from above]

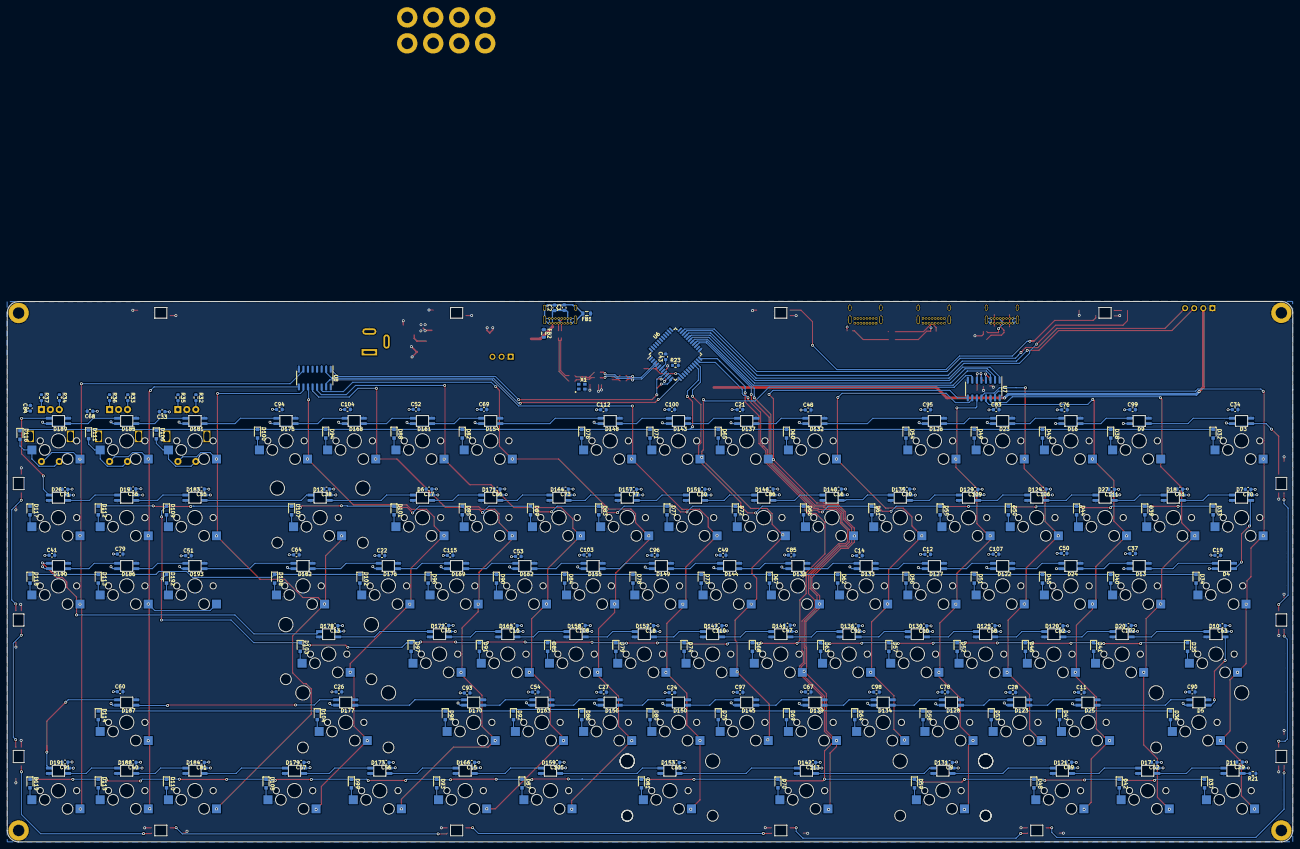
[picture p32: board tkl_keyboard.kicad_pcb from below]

Board: 2 copper layers, 358.8 x 150.8 mm, 484 parts (209 on the bottom side), 283 nets.

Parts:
C1, C4: 10uF; C_0603_1608Metric
C2, C6, C7, C43, C46, C116, C117, C118, C120: 1uF; C_0603_1608Metric
C3, C5, C8, C9, C10, C11, C12, C13, C14, C15, C16, C17, C18, C19, C20, C21, C22, C23, C24, C25, C26, C27, C28, C29, C30, C31, C32, C33, C34, C35, C36, C37, C38, C39, C40, C41, C42, C44, C45, C47, C48, C49, C50, C51, C52, C53, C54, C55, C56, C57, C58, C59, C60, C61, C62, C63, C64, C65, C66, C67, C68, C69, C70, C71, C72, C73, C74, C75, C76, C77, C78, C79, C80, C81, C82, C83, C84, C85, C86, C87, C88, C89, C90, C91, C92, C93, C94, C95, C96, C97, C98, C99, C100, C101, C102, C103, C104, C105, C106, C107, C108, C109, C110, C111, C112, C113, C114, C115, C119: 100nF; C_0603_1608Metric
C121: 47uF; C_1210_3225Metric
D1: D; DO-214AC
D2: UG_4; SK6812-MINI-E
D3: K0; SK6812-MINI-E
D4: K32; SK6812-MINI-E
D5: K63; SK6812-MINI-E
D6: K28; SK6812-MINI-E
D7: K16; SK6812-MINI-E
D8: UG_5; SK6812-MINI-E
D9: K1; SK6812-MINI-E
D10: K48; SK6812-MINI-E
D11: K77; SK6812-MINI-E
D12: K29; SK6812-MINI-E
D13: K33; SK6812-MINI-E
D14: UG_0; SK6812-MINI-E
D15: UG_6; SK6812-MINI-E
D16: K2; SK6812-MINI-E
D17: K64; SK6812-MINI-E
D18: K17; SK6812-MINI-E
D19: K30; SK6812-MINI-E
D20: K49; SK6812-MINI-E
D21: UG_1; SK6812-MINI-E
D22: UG_7; SK6812-MINI-E
D23: K3; SK6812-MINI-E
D24: K34; SK6812-MINI-E
D25: K65; SK6812-MINI-E
D26: K31; SK6812-MINI-E
D27: K18; SK6812-MINI-E
D28: UG_2; SK6812-MINI-E
D29: UG_8; SK6812-MINI-E
D30: UG_3; SK6812-MINI-E
D31: UG_9; SK6812-MINI-E
D32, D33, D34, D35, D36, D37, D38, D39, D40, D41, D42, D43, D44, D45, D46, D47, D48, D49, D50, D51, D52, D53, D54, D55, D56, D57, D58, D59, D60, D61, D62, D63, D64, D65, D66, D67, D68, D69, D70, D71, D72, D73, D74, D75, D76, D77, D78, D79, D80, D81, D82, D83, D84, D85, D86, D87, D88, D89, D90, D91, D92, D93, D94, D95, D96, D97, D98, D99, D100, D101, D102, D103, D104, D105, D106, D107, D108, D109, D110, D111, D112, D113, D114, D115, D116, D117, D118, D119, D192: D; SOD323_HS
D120: K50; SK6812-MINI-E
D121: K78; SK6812-MINI-E
D122: K35; SK6812-MINI-E
D123: K66; SK6812-MINI-E
D124: K19; SK6812-MINI-E
D125: K51; SK6812-MINI-E
D126: K4; SK6812-MINI-E
D127: K36; SK6812-MINI-E
D128: K67; SK6812-MINI-E
D129: K20; SK6812-MINI-E
D130: K52; SK6812-MINI-E
D131: K79; SK6812-MINI-E
D132: K5; SK6812-MINI-E
D133: K37; SK6812-MINI-E
D134: K68; SK6812-MINI-E
D135: K21; SK6812-MINI-E
D136: K53; SK6812-MINI-E
D137: K6; SK6812-MINI-E
D138: K38; SK6812-MINI-E
D139: K69; SK6812-MINI-E
D140: K22; SK6812-MINI-E
D141: K54; SK6812-MINI-E
D142: K80; SK6812-MINI-E
D143: K7; SK6812-MINI-E
D144: K39; SK6812-MINI-E
D145: K70; SK6812-MINI-E
D146: K23; SK6812-MINI-E
D147: K55; SK6812-MINI-E
D148: K8; SK6812-MINI-E
D149: K40; SK6812-MINI-E
D150: K71; SK6812-MINI-E
D151: K24; SK6812-MINI-E
D152: K56; SK6812-MINI-E
D153: K81; SK6812-MINI-E
D154: K9; SK6812-MINI-E
D155: K41; SK6812-MINI-E
D156: K72; SK6812-MINI-E
D157: K25; SK6812-MINI-E
D158: K57; SK6812-MINI-E
D159: K82; SK6812-MINI-E
D160: UG_10; SK6812-MINI-E
D161: K10; SK6812-MINI-E
D162: K42; SK6812-MINI-E
D163: K73; SK6812-MINI-E
D164: K26; SK6812-MINI-E
D165: K58; SK6812-MINI-E
D166: K83; SK6812-MINI-E
D167: UG_11; SK6812-MINI-E
D168: K11; SK6812-MINI-E
D169: K43; SK6812-MINI-E
D170: K74; SK6812-MINI-E
D171: K27; SK6812-MINI-E
D172: K59; SK6812-MINI-E
D173: K84; SK6812-MINI-E
D174: UG_12; SK6812-MINI-E
D175: K12; SK6812-MINI-E
D176: K44; SK6812-MINI-E
D177: K75; SK6812-MINI-E
D178: K60; SK6812-MINI-E
D179: K85; SK6812-MINI-E
D180: UG_13; SK6812-MINI-E
D181: K13; SK6812-MINI-E
D182: K45; SK6812-MINI-E
D183: K61; SK6812-MINI-E
D184: K86; SK6812-MINI-E
D185: K14; SK6812-MINI-E
D186: K46; SK6812-MINI-E
D187: K76; SK6812-MINI-E
D188: K87; SK6812-MINI-E
D189: K15; SK6812-MINI-E
D190: K47; SK6812-MINI-E
D191: K88; SK6812-MINI-E
D193: K62; SK6812-MINI-E
D194: LED; D_0603_1608Metric
FB1, FB2, FB3: Ferrite_Bead; L_0805_2012Metric
H1, H2, H3, H4, H5, H6, H7, H8, H9, H10, H11, H12: MountingHole_Pad; MountingHole_3.2mm_M3_ISO7380_Pad
J1, J2, J3, J4: USB_C_Receptacle_USB2.0; USB_C_Receptacle_GCT_USB4085
J5: Conn_02x03_Odd_Even; ISP_POGO
J6: Conn_01x04_Female; OLED_128_64
J7: Barrel_Jack_MountingPin; BarrelJack_Wuerth_6941xx301002
J8: Conn_01x03_Male; PinHeader_1x03_P2.54mm_Vertical
L1: L_Core_Iron_Coupled_1423; SMM2012E
L2: L; L_10.4x10.4_H4.8
R1, R2: 5K1; R_0603_1608Metric
R3: 330R; R_0603_1608Metric
R5, R6, R12, R13, R14, R15, R16, R17, R18, R19: 22R; R_0603_1608Metric
R8, R9, R22, R23, R24, R25, R26, R27, R28, R29, R32, R33, R34, R35, R36, R37: 10K; R_0603_1608Metric
R10, R11, R30, R31: 4K7; R_0603_1608Metric
R20, R21: Rt; R_0603_1608Metric
R38, R39: OPT; R_0603_1608Metric
SW1: SW_Push; SW_SPST_B3U-1000P
SW2: K0; CherryMX_1.00u_PCB_KailhSocket
SW3: K16; CherryMX_1.00u_PCB_KailhSocket
SW4: K32; CherryMX_1.50u_PCB_KailhSocket
SW5: K48; CherryMX_1.75u_PCB_KailhSocket
SW6: K63; CherryMX_2.25u_PCB_KailhSocket_StabWireBottom
SW7: K77; CherryMX_1.25u_PCB_KailhSocket
SW8: K1; CherryMX_1.00u_PCB_KailhSocket
SW9: K17; CherryMX_1.00u_PCB_KailhSocket
SW10: K33; CherryMX_1.00u_PCB_KailhSocket
SW11: K49; CherryMX_1.00u_PCB_KailhSocket
SW12: K64; CherryMX_1.25u_PCB_KailhSocket
SW13: K2; CherryMX_1.00u_PCB_KailhSocket
SW14: K18; CherryMX_1.00u_PCB_KailhSocket
SW15: K34; CherryMX_1.00u_PCB_KailhSocket
SW16: K50; CherryMX_1.00u_PCB_KailhSocket
SW17: K65; CherryMX_1.00u_PCB_KailhSocket
SW18: K78; CherryMX_1.25u_PCB_KailhSocket
SW19: K3; CherryMX_1.00u_PCB_KailhSocket
SW20: K19; CherryMX_1.00u_PCB_KailhSocket
SW21: K35; CherryMX_1.00u_PCB_KailhSocket
SW22: K51; CherryMX_1.00u_PCB_KailhSocket
SW23: K66; CherryMX_1.00u_PCB_KailhSocket
SW24: K4; CherryMX_1.00u_PCB_KailhSocket
SW25: K20; CherryMX_1.00u_PCB_KailhSocket
SW26: K36; CherryMX_1.00u_PCB_KailhSocket
SW27: K52; CherryMX_1.00u_PCB_KailhSocket
SW28: K67; CherryMX_1.00u_PCB_KailhSocket
SW29: K79; CherryMX_2.25u_PCB_KailhSocket_StabWireBottom
SW30: K5; CherryMX_1.00u_PCB_KailhSocket
SW31: K21; CherryMX_1.00u_PCB_KailhSocket
SW32: K37; CherryMX_1.00u_PCB_KailhSocket
SW33: K53; CherryMX_1.00u_PCB_KailhSocket
SW34: K68; CherryMX_1.00u_PCB_KailhSocket
SW35: K6; CherryMX_1.00u_PCB_KailhSocket
SW36: K22; CherryMX_1.00u_PCB_KailhSocket
SW37: K38; CherryMX_1.00u_PCB_KailhSocket
SW38: K54; CherryMX_1.00u_PCB_KailhSocket
SW39: K69; CherryMX_1.00u_PCB_KailhSocket
SW40: K80; CherryMX_6.25u_PCB_KailhSocket_StabWireBottom
SW41: K7; CherryMX_1.00u_PCB_KailhSocket
SW42: K23; CherryMX_1.00u_PCB_KailhSocket
SW43: K39; CherryMX_1.00u_PCB_KailhSocket
SW44: K55; CherryMX_1.00u_PCB_KailhSocket
SW45: K70; CherryMX_1.00u_PCB_KailhSocket
SW46: K8; CherryMX_1.00u_PCB_KailhSocket
SW47: K24; CherryMX_1.00u_PCB_KailhSocket
SW48: K40; CherryMX_1.00u_PCB_KailhSocket
SW49: K56; CherryMX_1.00u_PCB_KailhSocket
SW50: K71; CherryMX_1.00u_PCB_KailhSocket
SW51: K81; CherryMX_2.25u_PCB_KailhSocket_StabWireBottom
SW52: K9; CherryMX_1.00u_PCB_KailhSocket
SW53: K25; CherryMX_1.00u_PCB_KailhSocket
SW54: K41; CherryMX_1.00u_PCB_KailhSocket
SW55: K57; CherryMX_1.00u_PCB_KailhSocket
SW56: K72; CherryMX_1.00u_PCB_KailhSocket
SW57: K82; CherryMX_1.25u_PCB_KailhSocket
SW58: K10; CherryMX_1.00u_PCB_KailhSocket
SW59: K26; CherryMX_1.00u_PCB_KailhSocket
SW60: K42; CherryMX_1.00u_PCB_KailhSocket
SW61: K58; CherryMX_1.00u_PCB_KailhSocket
SW62: K73; CherryMX_1.00u_PCB_KailhSocket
SW63: K83; CherryMX_1.25u_PCB_KailhSocket
SW64: K11; CherryMX_1.00u_PCB_KailhSocket
SW65: K27; CherryMX_1.00u_PCB_KailhSocket
SW66: K43; CherryMX_1.00u_PCB_KailhSocket
SW67: K59; CherryMX_1.00u_PCB_KailhSocket
SW68: K74; CherryMX_1.00u_PCB_KailhSocket
SW69: K84; CherryMX_1.25u_PCB_KailhSocket
SW70: K12; CherryMX_1.00u_PCB_KailhSocket
SW71: K28; CherryMX_1.00u_PCB_KailhSocket
SW72: K44; CherryMX_1.00u_PCB_KailhSocket
SW73: K60; CherryMX_2.25u_PCB_KailhSocket_StabWireBottom
SW74: K75; CherryMX_2.75u_PCB_KailhSocket_StabWireBottom
SW75: K85; CherryMX_1.25u_PCB_KailhSocket
SW76: K13; CherryMX_1.00u_PCB_KailhSocket
SW77: K29; CherryMX_2.00u_PCB_KailhSocket_StabWireBottom
SW78: K45; CherryMX_1.50u_PCB_KailhSocket
SW79: K61; CherryMX_1.00u_PCB_KailhSocket
SW80: K86; CherryMX_1.00u_PCB_KailhSocket
SW81: K14; CherryMX_1.00u_PCB_KailhSocket
SW82: K30; CherryMX_1.00u_PCB_KailhSocket
SW83: K46; CherryMX_1.00u_PCB_KailhSocket
SW84: K76; CherryMX_1.00u_PCB_KailhSocket
SW85: K87; CherryMX_1.00u_PCB_KailhSocket
SW86: K15; CherryMX_1.00u_PCB_KailhSocket
SW87: K31; CherryMX_1.00u_PCB_KailhSocket
SW88: K47; CherryMX_1.00u_PCB_KailhSocket
SW89: K88; CherryMX_1.00u_PCB_KailhSocket
SW90, SW91, SW92: Rotary_Encoder_Switch; RotaryEncoder_Alps_EC11E-Switch_Vertical_H20mm
SW93: K62; CherryMX_1.00u_PCB_KailhSocket
TP1, TP2, TP3: TestPoint; TestPoint_Pad_D1.0mm
U1, U3, U5: SRV05-4; SOT-23-6
U2: ADP2303ARDZ-5.0; SOIC-8-1EP_3.9x4.9mm_P1.27mm_EP2.29x3mm
U4: TUSB2046b
U6: ATmega32U4-AU; TQFP-44_10x10mm_P0.8mm
U7, U8: CD74HC238; SOIC-16_3.9x9.9mm_P1.27mm
U9: TCR2EF33; TCR2EF33_SOT25
X1: 625L3C006M00000
X2: KC2016K

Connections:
+3V3: C7.1, C8.1, C42.1, C44.1, C45.1, C46.1, C120.1, D194.2, J5.2, J6.2, R8.2, R10.2, R11.2, R22.1, R26.2, R29.2, R30.1, R31.1, R32.1, R33.1, R34.1, R35.1, R36.1, R37.1, TP2.1, U4.3, U4.10, U4.14, U4.18, U4.22, U4.25, U6.2, U6.14, U6.24, U6.34, U6.42, U6.44, U7.16, U8.16, U9.5, X1.1, X1.4, X2.1, X2.4
+5V: C5.1, C9.1, C10.1, C11.1, C12.1, C13.1, C14.1, C15.1, C16.1, C17.1, C18.1, C19.1, C20.1, C21.1, C22.1, C23.1, C24.1, C25.1, C26.1, C27.1, C28.1, C29.1, C30.1, C31.1, C32.1, C33.1, C34.1, C35.1, C36.1, C37.1, C38.1, C39.1, C40.1, C41.1, C47.1, C48.1, C49.1, C50.1, C51.1, C52.1, C53.1, C54.1, C55.1, C56.1, C57.1, C58.1, C59.1, C60.1, C61.1, C62.1, C63.1, C64.1, C65.1, C66.1, C67.1, C68.1, C69.1, C70.1, C71.1, C72.1, C73.1, C74.1, C75.1, C76.1, C77.1, C78.1, C79.1, C80.1, C81.1, C82.1, C83.1, C84.1, C85.1, C86.1, C87.1, C88.1, C89.1, C90.1, C91.1, C92.1, C93.1, C94.1, C95.1, C96.1, C97.1, C98.1, C99.1, C100.1, C101.1, C102.1, C103.1, C104.1, C105.1, C106.1, C107.1, C108.1, C109.1, C110.1, C111.1, C112.1, C113.1, C114.1, C115.1, C116.1, C117.1, C118.1, D2.1, D3.1, D4.1, D5.1, D6.1, D7.1, D8.1, D9.1, D10.1, D11.1, D12.1, D13.1, D14.1, D15.1, D16.1, D17.1, D18.1, D19.1, D20.1, D21.1, D22.1, D23.1, D24.1, D25.1, D26.1, D27.1, D28.1, D29.1, D30.1, D31.1, D120.1, D121.1, D122.1, D123.1, D124.1, D125.1, D126.1, D127.1, D128.1, D129.1, D130.1, D131.1, D132.1, D133.1, D134.1, D135.1, D136.1, D137.1, D138.1, D139.1, D140.1, D141.1, D142.1, D143.1, D144.1, D145.1, D146.1, D147.1, D148.1, D149.1, D150.1, D151.1, D152.1, D153.1, D154.1, D155.1, D156.1, D157.1, D158.1, D159.1, D160.1, D161.1, D162.1, D163.1, D164.1, D165.1, D166.1, D167.1, D168.1, D169.1, D170.1, D171.1, D172.1, D173.1, D174.1, D175.1, D176.1, D177.1, D178.1, D179.1, D180.1, D181.1, D182.1, D183.1, D184.1, D185.1, D186.1, D187.1, D188.1, D189.1, D190.1, D191.1, D193.1, J2.A4, J2.A9, J2.B4, J2.B9, J3.A4, J3.A9, J3.B4, J3.B9, J4.A4, J4.A9, J4.B4, J4.B9, J8.2, TP3.1, U3.5, U5.5, U9.1, U9.3
+5V0_EXT: C121.1, J8.3, L2.2, U2.5
+5V0_USB: C3.1, FB3.1, J8.1
/Column Decoder/COLA[0]: U6.29, U7.1
/Column Decoder/COLA[1]: U6.28, U7.2
/Column Decoder/COLA[2]: U6.27, U7.3
/Column Decoder/COLA[3]: U6.8, U8.1
/Column Decoder/COLA[4]: U6.12, U8.2
/Column Decoder/COLA[5]: U6.1, U8.3
/Column Decoder/COL[0]: SW2.2, SW3.2, SW4.2, SW5.2, SW6.2, SW7.2, U7.15
/Column Decoder/COL[1]: SW8.2, SW9.2, SW10.2, SW11.2, SW12.2, U7.14
/Column Decoder/COL[2]: SW13.2, SW14.2, SW15.2, SW16.2, SW17.2, SW18.2, U7.13
/Column Decoder/COL[3]: SW19.2, SW20.2, SW21.2, SW22.2, SW23.2, U7.12
/Column Decoder/COL[4]: SW24.2, SW25.2, SW26.2, SW27.2, SW28.2, SW29.2, U7.11
/Column Decoder/COL[5]: SW30.2, SW31.2, SW32.2, SW33.2, SW34.2, U7.10
/Column Decoder/COL[6]: SW35.2, SW36.2, SW37.2, SW38.2, SW39.2, SW40.2, U7.9
/Column Decoder/COL[7]: SW41.2, SW42.2, SW43.2, SW44.2, SW45.2, U7.7
/Column Decoder/COL[8]: SW46.2, SW47.2, SW48.2, SW49.2, SW50.2, SW51.2, U8.15
/Column Decoder/COL[9]: SW52.2, SW53.2, SW54.2, SW55.2, SW56.2, SW57.2, U8.14
/Column Decoder/COL[10]: SW58.2, SW59.2, SW60.2, SW61.2, SW62.2, SW63.2, U8.13
/Column Decoder/COL[11]: SW64.2, SW65.2, SW66.2, SW67.2, SW68.2, SW69.2, U8.12
/Column Decoder/COL[12]: SW70.2, SW71.2, SW72.2, SW73.2, SW74.2, SW75.2, U8.11
/Misc/ENC_A[0]: R35.2, SW90.A, U6.41
/Misc/ENC_A[1]: R36.2, SW91.A, U6.39
/Misc/ENC_A[2]: R37.2, SW92.A, U6.37
/Misc/ENC_B[0]: R32.2, SW90.B, U6.40
/Misc/ENC_B[1]: R33.2, SW91.B, U6.38
/Misc/ENC_B[2]: R34.2, SW92.B, U6.36
/Misc/SCL: J6.4, R30.2, U6.32
/Misc/SDA: J6.3, R31.2, U6.31
/Power/DCDC_IN: C4.1, J7.1, U2.2, U2.3
/Power/SW: C119.2, D1.1, L2.1, U2.8
/Switches/ROW[0]: D32.1, D38.1, D43.1, D49.1, D54.1, D60.1, D65.1, D71.1, D76.1, D82.1, D88.1, D94.1, D100.1, D106.1, D111.1, D116.1, U6.19
/Switches/ROW[1]: D33.1, D39.1, D44.1, D50.1, D55.1, D61.1, D66.1, D72.1, D77.1, D83.1, D89.1, D95.1, D101.1, D107.1, D112.1, D117.1, U6.20
/Switches/ROW[2]: D34.1, D40.1, D45.1, D51.1, D56.1, D62.1, D67.1, D73.1, D78.1, D84.1, D90.1, D96.1, D102.1, D108.1, D113.1, D118.1, U6.22
/Switches/ROW[3]: D35.1, D41.1, D46.1, D52.1, D57.1, D63.1, D68.1, D74.1, D79.1, D85.1, D91.1, D97.1, D103.1, D109.1, D192.1, U6.21
/Switches/ROW[4]: D36.1, D47.1, D53.1, D58.1, D64.1, D69.1, D75.1, D80.1, D86.1, D92.1, D98.1, D104.1, D114.1, U6.25
/Switches/ROW[5]: D37.1, D42.1, D48.1, D59.1, D70.1, D81.1, D87.1, D93.1, D99.1, D105.1, D110.1, D115.1, D119.1, U6.26
/USB Downstream 0/USBD+: J2.A6, J2.B6, R12.1, U3.3
/USB Downstream 0/USBD-: J2.A7, J2.B7, R13.1, U3.4
/USB Downstream 1/USBD+: J3.A6, J3.B6, R14.1, U3.6
/USB Downstream 1/USBD-: J3.A7, J3.B7, R15.1, U3.1
/USB Downstream 2/USBD+: J4.A6, J4.B6, R16.1, U5.4
/USB Downstream 2/USBD-: J4.A7, J4.B7, R17.1, U5.3
/USB HUB/D1+: R12.2, U4.12
/USB HUB/D1-: R13.2, U4.11
/USB HUB/D2+: R14.2, U4.16
/USB HUB/D2-: R15.2, U4.15
/USB HUB/D3+: R16.2, U4.20
/USB HUB/D3-: R17.2, U4.19
/USB HUB/D4+: R18.2, U4.24
/USB HUB/D4-: R19.2, U4.23
/USB HUB/USB_DOWNSTREAM_LOCAL_OUT+: R18.1, R38.1, U6.4
/USB HUB/USB_DOWNSTREAM_LOCAL_OUT-: R19.1, R39.1, U6.3
/USB HUB/USB_UPSTREAM_IN+: R6.1, R38.2, U4.1
/USB HUB/USB_UPSTREAM_IN-: R5.1, R39.2, U4.2
/USB Upstream/CD+: J1.A6, J1.B6, L1.3, U1.1
/USB Upstream/CD-: J1.A7, J1.B7, L1.4, U1.6
/USB Upstream/D+: L1.2, R6.2
/USB Upstream/D-: L1.1, R5.2
/uController/RGB_DOUT: R20.1, U6.30
ENC_COL[0]: SW76.2, SW77.2, SW78.2, SW79.2, SW80.2, SW90.S2, U8.10
ENC_COL[1]: SW81.2, SW82.2, SW83.2, SW84.2, SW85.2, SW91.S2, SW93.2, U8.9
ENC_COL[2]: SW86.2, SW87.2, SW88.2, SW89.2, SW92.S2, U8.7
ENC_ROW[0]: D106.2, SW76.1, SW90.S1
ENC_ROW[1]: D111.2, SW81.1, SW91.S1
ENC_ROW[2]: D116.2, SW86.1, SW92.S1
GND: C3.2, C4.2, C5.2, C6.1, C7.2, C8.2, C9.2, C10.2, C11.2, C12.2, C13.2, C14.2, C15.2, C16.2, C17.2, C18.2, C19.2, C20.2, C21.2, C22.2, C23.2, C24.2, C25.2, C26.2, C27.2, C28.2, C29.2, C30.2, C31.2, C32.2, C33.2, C34.2, C35.2, C36.2, C37.2, C38.2, C39.2, C40.2, C41.2, C42.2, C43.2, C44.2, C45.2, C46.2, C47.2, C48.2, C49.2, C50.2, C51.2, C52.2, C53.2, C54.2, C55.2, C56.2, C57.2, C58.2, C59.2, C60.2, C61.2, C62.2, C63.2, C64.2, C65.2, C66.2, C67.2, C68.2, C69.2, C70.2, C71.2, C72.2, C73.2, C74.2, C75.2, C76.2, C77.2, C78.2, C79.2, C80.2, C81.2, C82.2, C83.2, C84.2, C85.2, C86.2, C87.2, C88.2, C89.2, C90.2, C91.2, C92.2, C93.2, C94.2, C95.2, C96.2, C97.2, C98.2, C99.2, C100.2, C101.2, C102.2, C103.2, C104.2, C105.2, C106.2, C107.2, C108.2, C109.2, C110.2, C111.2, C112.2, C113.2, C114.2, C115.2, C116.2, C117.2, C118.2, C120.2, C121.2, D1.2, D2.3, D3.3, D4.3, D5.3, D6.3, D7.3, D8.3, D9.3, D10.3, D11.3, D12.3, D13.3, D14.3, D15.3, D16.3, D17.3, D18.3, D19.3, D20.3, D21.3, D22.3, D23.3, D24.3, D25.3, D26.3, D27.3, D28.3, D29.3, D30.3, D31.3, D120.3, D121.3, D122.3, D123.3, D124.3, D125.3, D126.3, D127.3, D128.3, D129.3, D130.3, D131.3, D132.3, D133.3, D134.3, D135.3, D136.3, D137.3, D138.3, D139.3, D140.3, D141.3, D142.3, D143.3, D144.3, D145.3, D146.3, D147.3, D148.3, D149.3, D150.3, D151.3, D152.3, D153.3, D154.3, D155.3, D156.3, D157.3, D158.3, D159.3, D160.3, D161.3, D162.3, D163.3, D164.3, D165.3, D166.3, D167.3, D168.3, D169.3, D170.3, D171.3, D172.3, D173.3, D174.3, D175.3, D176.3, D177.3, D178.3, D179.3, D180.3, D181.3, D182.3, D183.3, D184.3, D185.3, D186.3, D187.3, D188.3, D189.3, D190.3, D191.3, D193.3, FB1.1, FB2.1, H1.1, H2.1, H3.1, H4.1, H5.1, H6.1, H7.1, H8.1, H9.1, H10.1, H11.1, H12.1, J2.A1, J2.A12, J2.B1, J2.B12, J2.S1, J3.A1, J3.A12, J3.B1, J3.B12, J3.S1, J4.A1, J4.A12, J4.B1, J4.B12, J4.S1, J5.6, J6.1, J7.2, R1.1, R2.1, R3.1, R9.1, R21.1, R23.2, R24.2, R25.2, R27.2, R28.2, SW1.2, SW90.C, SW91.C, SW92.C, TP1.1, U1.2, U2.7, U2.9, U3.2, U4.7, U4.27, U4.28, U4.31, U5.2, U6.5, U6.15, U6.23, U6.35, U6.43, U7.8, U8.8, U9.2, X1.2, X2.2
MISO: J5.1, U6.11
MOSI: J5.4, U6.10
unnamed: C1.2, C2.2, FB1.2, FB2.2, J1.A1, J1.A12, J1.B1, J1.B12, J1.S1
unnamed: C6.2, R10.1, U4.4
unnamed: C43.1, U6.6
unnamed: C119.1, U2.1
unnamed: D2.2, D8.4
unnamed: D2.4, D30.2
unnamed: D3.2, D9.4
unnamed: D4.4, D7.2
unnamed: D5.4, D10.2
unnamed: D10.4, D20.2
unnamed: D11.2, R21.2
unnamed: D11.4, D17.2
unnamed: D6.4, D12.2
unnamed: D12.4, D183.2
unnamed: D13.2, D24.4
unnamed: D4.2, D13.4
unnamed: D14.2, D21.4
unnamed: D14.4, R20.2
unnamed: D15.2, D22.4
unnamed: D8.2, D15.4
unnamed: D16.2, D23.4
unnamed: D9.2, D16.4
unnamed: D7.4, D18.2
unnamed: D18.4, D27.2
unnamed: D19.4, D26.2
unnamed: D21.2, D28.4
unnamed: D22.2, D29.4
unnamed: D5.2, D25.4
unnamed: D28.2, D30.4
unnamed: D29.2, D31.4
unnamed: D32.2, SW2.1
unnamed: D33.2, SW3.1
unnamed: D34.2, SW4.1
unnamed: D35.2, SW5.1
unnamed: D36.2, SW6.1
unnamed: D37.2, SW7.1
unnamed: D38.2, SW8.1
unnamed: D39.2, SW9.1
unnamed: D40.2, SW10.1
unnamed: D41.2, SW11.1
unnamed: D42.2, SW12.1
unnamed: D43.2, SW13.1
unnamed: D44.2, SW14.1
unnamed: D45.2, SW15.1
unnamed: D46.2, SW16.1
unnamed: D47.2, SW17.1
unnamed: D48.2, SW18.1
unnamed: D49.2, SW19.1
unnamed: D50.2, SW20.1
unnamed: D51.2, SW21.1
unnamed: D52.2, SW22.1
unnamed: D53.2, SW23.1
unnamed: D54.2, SW24.1
unnamed: D55.2, SW25.1
unnamed: D56.2, SW26.1
unnamed: D57.2, SW27.1
unnamed: D58.2, SW28.1
unnamed: D59.2, SW29.1
unnamed: D60.2, SW30.1
unnamed: D61.2, SW31.1
unnamed: D62.2, SW32.1
unnamed: D63.2, SW33.1
unnamed: D64.2, SW34.1
unnamed: D65.2, SW35.1
unnamed: D66.2, SW36.1
unnamed: D67.2, SW37.1
unnamed: D68.2, SW38.1
unnamed: D69.2, SW39.1
unnamed: D70.2, SW40.1
unnamed: D71.2, SW41.1
unnamed: D72.2, SW42.1
unnamed: D73.2, SW43.1
unnamed: D74.2, SW44.1
unnamed: D75.2, SW45.1
unnamed: D76.2, SW46.1
unnamed: D77.2, SW47.1
unnamed: D78.2, SW48.1
unnamed: D79.2, SW49.1
unnamed: D80.2, SW50.1
unnamed: D81.2, SW51.1
unnamed: D82.2, SW52.1
unnamed: D83.2, SW53.1
unnamed: D84.2, SW54.1
unnamed: D85.2, SW55.1
unnamed: D86.2, SW56.1
unnamed: D87.2, SW57.1
unnamed: D88.2, SW58.1
unnamed: D89.2, SW59.1
unnamed: D90.2, SW60.1
unnamed: D91.2, SW61.1
unnamed: D92.2, SW62.1
unnamed: D93.2, SW63.1
unnamed: D94.2, SW64.1
unnamed: D95.2, SW65.1
unnamed: D96.2, SW66.1
unnamed: D97.2, SW67.1
unnamed: D98.2, SW68.1
unnamed: D99.2, SW69.1
unnamed: D100.2, SW70.1
unnamed: D101.2, SW71.1
unnamed: D102.2, SW72.1
unnamed: D103.2, SW73.1
unnamed: D104.2, SW74.1
unnamed: D105.2, SW75.1
unnamed: D107.2, SW77.1
unnamed: D108.2, SW78.1
unnamed: D109.2, SW79.1
unnamed: D110.2, SW80.1
unnamed: D112.2, SW82.1
unnamed: D113.2, SW83.1
unnamed: D114.2, SW84.1
unnamed: D115.2, SW85.1
unnamed: D117.2, SW87.1
unnamed: D118.2, SW88.1
unnamed: D119.2, SW89.1
unnamed: D20.4, D120.2
unnamed: D120.4, D125.2
unnamed: D17.4, D121.2
unnamed: D121.4, D131.2
unnamed: D122.2, D127.4
unnamed: D24.2, D122.4
unnamed: D123.2, D128.4
unnamed: D25.2, D123.4
unnamed: D27.4, D124.2
unnamed: D124.4, D129.2
unnamed: D125.4, D130.2
unnamed: D126.2, D132.4
unnamed: D23.2, D126.4
unnamed: D127.2, D133.4
unnamed: D128.2, D134.4
unnamed: D129.4, D135.2
unnamed: D130.4, D136.2
unnamed: D131.4, D142.2
unnamed: D132.2, D137.4
unnamed: D133.2, D138.4
unnamed: D134.2, D139.4
unnamed: D135.4, D140.2
unnamed: D136.4, D141.2
unnamed: D137.2, D143.4
unnamed: D138.2, D144.4
unnamed: D139.2, D145.4
unnamed: D140.4, D146.2
unnamed: D141.4, D147.2
unnamed: D142.4, D153.2
unnamed: D143.2, D148.4
unnamed: D144.2, D149.4
unnamed: D145.2, D150.4
unnamed: D146.4, D151.2
unnamed: D147.4, D152.2
unnamed: D148.2, D154.4
unnamed: D149.2, D155.4
unnamed: D150.2, D156.4
unnamed: D151.4, D157.2
unnamed: D152.4, D158.2
unnamed: D153.4, D159.2
unnamed: D154.2, D161.4
unnamed: D155.2, D162.4
unnamed: D156.2, D163.4
unnamed: D157.4, D164.2
unnamed: D158.4, D165.2
unnamed: D159.4, D166.2
unnamed: D160.2, D167.4
unnamed: D31.2, D160.4
unnamed: D161.2, D168.4
unnamed: D162.2, D169.4
unnamed: D163.2, D170.4
unnamed: D164.4, D171.2
unnamed: D165.4, D172.2
unnamed: D166.4, D173.2
unnamed: D167.2, D174.4
unnamed: D168.2, D175.4
unnamed: D169.2, D176.4
unnamed: D170.2, D177.4
unnamed: D6.2, D171.4
unnamed: D172.4, D178.2
unnamed: D173.4, D179.2
unnamed: D174.2, D180.4
unnamed: D175.2, D181.4
unnamed: D176.2, D182.4
unnamed: D177.2, D187.4
unnamed: D178.4, D190.2
unnamed: D179.4, D184.2
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

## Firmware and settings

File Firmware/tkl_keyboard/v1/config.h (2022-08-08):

#pragma once

#include "config_common.h"

/* USB Device descriptor parameter */
#define VENDOR_ID       0x1234
#define PRODUCT_ID      0x5678
#define DEVICE_VER      0x0000
#define MANUFACTURER    Alex Binos
#define PRODUCT         tkl_keyboard

/* Switch matrix dimensions */
#define MATRIX_ROWS 6
#define MATRIX_COLS 16
#define MATRIX_COL_CONTROL_PINS 6
#define MATRIX_COL_ENABLE_PINS 2

/* Micro controller pins */
#define MATRIX_ROW_PINS { C6, C7, D3, D2, D4, D6 }
#define MATRIX_COL_PINS { B5, B4, D7, E6, B0, B7 }
#define MATRIX_COL_ENABLES { F1, F0 }
#define UNUSED_PINS { E2, F4, F5, F6, F7}

/* COL2ROW, ROW2COL*/
#define DIODE_DIRECTION ROW2COL

/* RGB array */
#define RGB_DI_PIN B6
#define RGBLED_NUM 14
#define RGBLIGHT_HUE_STEP 8         // HSV steps for animations
#define RGBLIGHT_SAT_STEP 8
#define RGBLIGHT_VAL_STEP 8
#define RGBLIGHT_LIMIT_VAL 128      // Half brightness to save power
#define RGBLIGHT_DEFAULT_MODE RGBLIGHT_MODE_STATIC_LIGHT
#define RGBLIGHT_ANIMATIONS         // For more options see: https://beta.docs.qmk.fm/using-qmk/hardware-features/lighting/feature_rgblight

/* Caps LED (active low) */
#define LED_CAPS_LOCK_PIN D5
#define LED_PIN_ON_STATE 0

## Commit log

2021-08-25 schematic done
    [Decoder.sch, LEDs.sch, Misc.sch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]
2021-08-26 Keyswitch, LED and diode placement done
    [LEDs.sch, Switches.sch, USB_DOWNSTREAM.sch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]
2021-08-29 LEDs and diodes routed
    [Decoder.sch, LEDs.sch, Misc.sch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]
2021-08-29 Switch matrix routed
    [Decoder.sch, Switches.sch, tkl_keyboard.kicad_pcb]
2021-08-31 Rows and columns routed to controller. Extended top board edge to fit OLED. Removed optional resistors around CMC.
    [LEDs.sch, Misc.sch, Switches.sch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]
2021-09-04 Updating schematic
    [Decoder.sch, LEDs.sch, Misc.sch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]
2021-09-07 Power supply routed
    [Power.sch, tkl_keyboard.kicad_pcb, uController.sch]
2021-09-07 First pass of routing done
    [Misc.sch, Power.sch, USB_HUB.sch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]
2021-09-09 Fixing power/ground plane connections. Tidying some routing.
    [uController.sch]
2021-09-12 Cleaning up silk layers, Adding pin 1 markers and text
2021-09-12 Added some missing capacitors, Fixed DC jack footprint connections
    [Decoder.sch, LEDs.sch, Power.sch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]
2021-09-13 Adding DXFs
    [mx_key_frame_swillkb.dxf, tkl_keyboard-B_CrtYd.dxf, tkl_keyboard-Dwgs_User.dxf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]
2021-09-22 Fixing USB circuit, adding data line resistors as per AN-5052
    [USB_DOWNSTREAM.sch, USB_UPSTREAM.sch, uController.sch]
2021-09-23 Changing diode direction: row to column
    [Decoder.sch, Switches.sch]
2021-09-23 Updating board with diode changes, rows routed
2021-09-24 Tidying traces and silk, passing DRC
2021-09-24 Tidying schematic
    [Decoder.sch, LEDs.sch, Misc.sch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]
2021-09-26 Generating gerbers
    [USB_DOWNSTREAM.sch, USB_HUB.sch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]
2022-05-21 Removing redundant files
    [Switches - Copy.sch, tkl_keyboard_placement.kicad_pcb]
2022-05-21 Adding mechanical files
    [tkl_bottom_left.STL, tkl_bottom_middle.STL, tkl_bottom_right.STL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]
2022-05-21 Adding schematic pdf
2022-05-21 Hardware version 0
    [Decoder.sch, LEDs.sch, Misc.sch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]
2022-05-21 Hardware version 1 initial commit
    [Decoder.sch, LEDs.sch, Misc.sch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]
2022-05-21 Updating hardware versions
    [Decoder.sch, LEDs.sch, Misc.sch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]
2022-05-21 Updating hardware design Moved I2C lines Routed line decoder enable lines Removed line decoder strap resistors Rounded corners on planes Disconnected mounting holes from ground
    [Decoder.sch, Misc.sch, Power.sch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]
2022-08-08 v1 gerbers
    [tkl_keyboard-B_Cu.gbr, tkl_keyboard-B_Mask.gbr, tkl_keyboard-B_Paste.gbr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]
2022-08-08 Generating v1 schematic
2022-08-09 Updating DXFs
    [tkl_keyboard-B_CrtYd.dxf, tkl_keyboard-Dwgs_User.dxf, tkl_keyboard-F_CrtYd.dxf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]
2022-08-09 v1 keyframe
    [tkl_keyframe_left.STL, tkl_keyframe_middle.STL, tkl_keyframe_right.STL]
2022-08-09 Edge cuts DXF
    [tkl_keyboard-Edge_Cuts.dxf]
2022-08-09 v1 case and stand
    [tkl_case_left.STL, tkl_case_middle.STL, tkl_case_right.STL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]
2022-08-11 Increasing cut width between sections
    [tkl_case_left.STL, tkl_case_middle.STL, tkl_case_right.STL]
2022-08-11 Moving v0 case files
    [tkl_bottom_left.STL, tkl_bottom_middle.STL, tkl_bottom_right.STL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]
2022-10-15 Adding cutout for power selector jumper
    [tkl_keyframe_middle.STL]
2022-11-14 Adding encoder fix images
